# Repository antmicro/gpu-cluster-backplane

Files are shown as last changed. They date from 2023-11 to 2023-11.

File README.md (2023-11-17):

# GPU cluster backplane

Copyright (c) 2023 [Antmicro](https://www.antmicro.com)

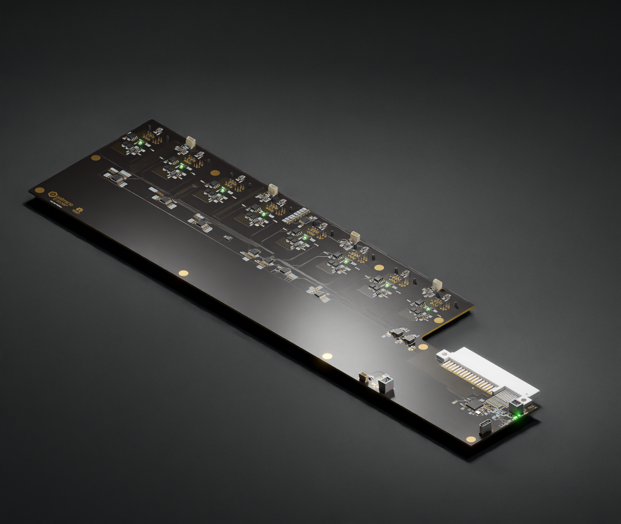
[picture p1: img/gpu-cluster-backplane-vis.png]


## Overview

This project contains open hardware design files for a PCB supporting power distribution in a cluster composed of GPUs.
This board has been derived from an open source [d166-e-psu-breakout](https://github.com/antmicro/d1600e-psu-breakout) created by Antmicro.
The GPU cluster backplane has been designed to be used with up to eight GPU units connected over a series [thunderbolt-gpu-adapters](https://github.com/antmicro/thunderbolt-gpu-adapter).
The design files for the board were prepared in KiCad 6.x.

## Key features

* Power supply distribution between eight expansion slots
* Built-in circuitry for driving cooling fans for the GPUs

## Project structure 

The main directory contains KiCad PCB project files, a LICENSE and a README.
The remaining files are stored in the following directories: 

* `lib` - contains the component libraries
* `img` - contains graphics for this README
* `doc` - contains board schematics in PDF format
* `assets` - contains visual assets for showcasing this design on [Open Hardware Portal](https://openhardware.antmicro.com) 

## License

This project is published under the [Apache-2.0](LICENSE) license.

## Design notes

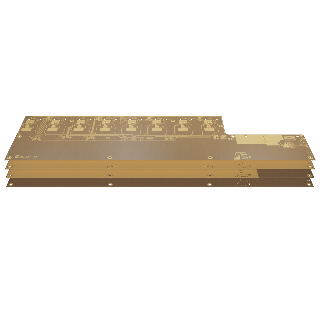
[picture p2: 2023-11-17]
assets/previews/layer1_thumbnail.webp

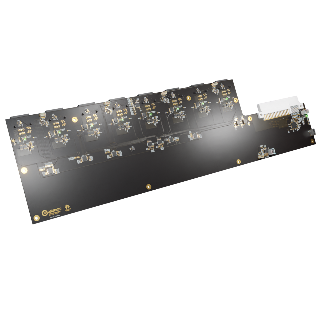
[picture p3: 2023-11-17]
assets/previews/leftT_thumbnail.png

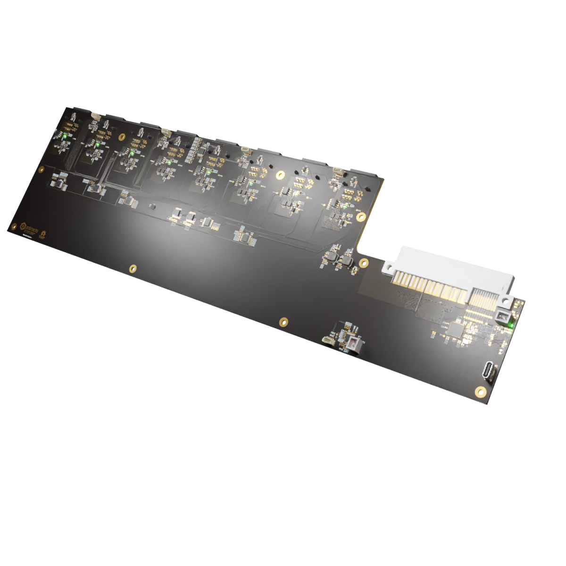
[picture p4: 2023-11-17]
assets/previews/rightT.webp

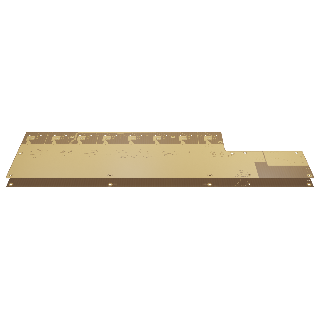
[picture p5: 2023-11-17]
assets/previews/layer3_thumbnail.webp

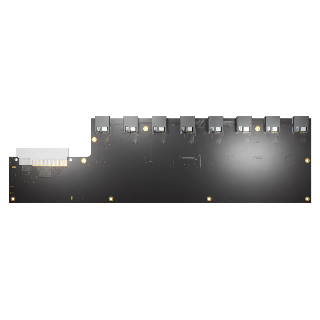
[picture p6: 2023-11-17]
assets/previews/orthoB_thumbnail.webp

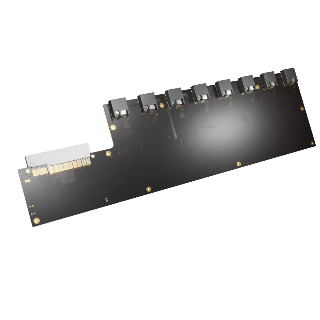
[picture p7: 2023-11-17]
assets/previews/leftB_thumbnail.png

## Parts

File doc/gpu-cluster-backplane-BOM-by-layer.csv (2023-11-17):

Reference | Quantity | Value | Footprint | Manufacturer | MPN | Layer
C1 C14 | 2 | C_10u_25V_0603 | C_0603_1608Metric | TDK | C1608X5R1E106M080AC | Top
C10 C11 C22 C23 | 4 | C_22u_16V_0603 | C_0603_1608Metric | Samsung Electro-Mechanics | CL10A226MO7JZNC | Top
C19 C92 | 2 | C_3u3_0402 | C_0402_1005Metric | TDK | C1005JB1A335K050BC | Top
C2 C59 C60 C70 C76 C77 | 6 | C_4u7_0402 | C_0402_1005Metric | Murata | GRM155R61A475MEAAD | Top
C25 C26 C27 C28 C29 C30 C31 C32 | 8 | C_10u_16V_0603 | C_0603_1608Metric | Murata | GRM188C81C106MA73D | Top
C3 C8 | 2 | C_18p_0402 | C_0402_1005Metric | Samsung Electro-Mechanics | CL05C180JB51PNC | Top
C45 C48 | 2 | C_1u_16V_0402 | C_0402_1005Metric | KEMET | C0402C105M4PACTU | Top
C5 C6 C7 C9 C12 C13 C15 C16 C17 C18 C20 C21 C24 C33 C34 C35 C36 C37 C38 C39 C40 C41 C42 C43 C44 C46 C47 C49 C50 C51 C52 C53 C54 C55 C57 C58 C61 C62 C63 C64 C66 C67 C68 C72 C75 C79 C80 C82 C84 C85 C86 C89 C93 C94 C95 C96 C97 C98 C99 C100 C101 C102 C103 C104 C105 | 65 | C_100n_0402 | C_0402_1005Metric | Murata | GRM155R61H104KE14D | Top
C56 C73 C74 C78 C87 C91 | 6 | C_2u2_0402 | C_0402_1005Metric | TDK | C1005X5R1A225K050BC | Top
C69 C71 | 2 | C_22p_0402 | C_0402_1005Metric | YAGEO | CC0402JRNPO9BN220 | Top
C81 C83 | 2 | C_16p_0402 | C_0402_1005Metric | Walsin | 0402N160J500CT | Top
C88 C90 | 2 | C_10p_0402 | C_0402_1005Metric | Murata | GCM1555C1H100GA16D | Top
D1 D2 D5 D12 D16 D19 D22 D25 D28 D31 D34 D41 | 12 | LED_G_0603_LG_L29K-G2J1-24-Z | LED_0603_1608Metric_G | OSRAM | LG L29K-G2J1-24-Z | Top
D3 D13 D14 | 3 | PESD5V0S2BQA | TPD2E009DRTR | Nexperia | PESD5V0S2BQA | Top
D36 D37 D38 D39 D44 | 5 | ESD9X5.0ST5G | SOD-923 | ON Semiconductor | ESD9X5.0ST5G | Top
D4 D15 D18 D21 D24 D27 D30 D33 | 8 |  |  |  |  | Top
D40 D43 | 2 | TPD2E009_SOT-9X3 | SOT-723 | Texas Instruments | TPD2E009DRTR | Top
D42 | 1 | LED_R_0603_KP-1608EC | LED_0603_1608Metric_R | Kingbright | KP-1608EC | Top
D6 D17 D20 D23 D26 D29 D32 D35 D45 | 9 | ESDA25P35-1U1M | ESDA25P35-1U1M | STMicroelectronics | ESDA25P35-1U1M | Top
D7 D8 D9 D10 D11 | 5 | 1N4148WS-7-F | SOD-323 | Diodes Incorporated | 1N4148WS-7-F | Top
FB1 FB2 FB10 | 3 | FB_600Z_0.5A_Murata-BLM18AG_0603 | FB_0603_1608Metric | Murata | BLM18AG601SN1D | Top
FB13 FB14 FB16 FB17 | 4 | FB_120Z_2A_Murata-BLM18PG_0603 | FB_0603_1608Metric | Murata | BLM18PG121SN1D | Top
FB3 FB4 | 2 | FB_30Z_8.5A_Murata-BLM21SN_0805 | FB_0805_2012Metric | Murata | BLM21SN300SZ1D | Top
FB5 FB6 FB7 FB8 FB9 | 5 | FB_120Z_3A_Murata-BLM18SG_0603 | FB_0603_1608Metric | Murata | BLM18SG121TN1D | Top
J17 J19 | 2 |  |  |  |  | Top
J18 | 1 | JST_SH_1x4_SM04B-SRSS-TB-LF-SN | Conn_JST_SH_1x4_SM04B-SRSS-TB-LF-SN | JST Automotive Connectors | SM04B-SRSS-TB(LF)(SN) | Top
J2 J9 | 2 | JST_XH_1x2_B2B-XH-A-LF-SN | Conn_JST_XH_1x2_B2B-XH-A-LF-SN | JST Automotive Connectors | B2B-XH-A(LF)(SN) | Top
J3 J4 J5 J6 J7 | 5 | JST_SH_1x4_BM04B-SRSS-TB-LF-SN | Conn_JST_SH_1x4_BM04B-SRSS-TB-LF-SN | JST Automotive Connectors | BM04B-SRSS-TB(LF)(SN) | Top
J8 | 1 | Socket_10107844-002LF | Socket_10107844-002LF | Amphenol | 10107844-002LF | Top
L1 L2 | 2 | L_3u3_4.1A_WE-LHMI-5030 | L_WE-LHMI-5030 | Würth Elektronik | 74437336033 | Top
MP1 MP2 MP3 MP4 MP5 MP6 MP7 MP8 MP9 | 9 | MP_Pad6mm_Drill3mm | MP_Pad6mm_Drill3mm |  |  | Top
N1 | 1 | antmicro_logo | antmicro-logo |  |  | Top
N2 | 1 | oshw_logo | oshw-logo |  |  | Top
Q1 Q4 Q5 Q6 Q7 Q8 Q11 Q14 Q17 Q20 Q23 Q26 | 12 | BSS138PW | SC70-3 | Nexperia | BSS138PW | Top
Q2 Q3 Q9 Q10 Q12 Q13 Q15 Q16 Q18 Q19 Q21 Q22 Q24 Q25 Q27 Q28 | 16 | SI7613DN-T1-GE3 | Vishay_PowerPAK_1212-8_Single | Vishay | SI7613DN-T1-GE3 | Top
Q29 | 1 | BC807-25W | SOT-323 | ON Semiconductor | SBC807-40WT1G | Top
R1 R2 | 2 | R_330R_0402 | R_0402_1005Metric | Bourns | CR0402-FX-3300GLF | Top
R10 R11 R12 R25 R29 R42 R52 R55 R63 R64 R65 R66 R67 R68 R69 R70 R71 R76 R77 R88 R91 R92 R94 R97 R98 R101 R129 R131 R132 R135 R137 R140 R164 R168 R170 R172 R174 R177 R178 R181 R183 R190 R194 R201 R205 R212 R216 R223 R227 R234 R238 R245 R249 R257 R258 R259 R260 R261 R263 R264 R273 | 61 | R_0R_0402 | R_0402_1005Metric | Panasonic | ERJ2GE0R00X | Top
R13 R14 R21 R102 R103 R136 R141 R160 R165 R175 R186 R191 R197 R202 R208 R213 R219 R224 R230 R235 R241 R246 | 22 | R_4k7_0402 | R_0402_1005Metric | Bourns | CR0402-FX-4701GLF | Top
R22 R161 R163 R187 R189 R198 R200 R209 R211 R220 R222 R231 R233 R242 R244 | 15 | R_2R_0402 | R_0402_1005Metric | Bourns | CR0402-FX-2R00GLF | Top
R256 R270 | 2 | R_470R_0402 | R_0402_1005Metric | Bourns | CR0402-FX-4700GLF | Top
R27 R166 R192 R203 R214 R225 R236 R247 R272 R278 R282 R286 R288 | 13 | R_100k_0402 | R_0402_1005Metric | Bourns | CR0402-FX-1003GLF | Top
R279 R280 | 2 | R_100R_0402 | R_0402_1005Metric | Bourns | CR0402-FX-1000GLF | Top
R28 R167 R193 R204 R215 R226 R237 R248 | 8 | R_15k_0.1%_0402 | R_0402_1005Metric | Panasonic | ERA-2ARB153X | Top
R299 | 1 | R_6k34_0402 | R_0402_1005Metric | Bourns | CR0402-FX-6341GLF | Top
R3 R87 R89 R105 R108 R111 R114 R117 R120 R123 R126 R252 R253 R289 R290 | 15 | R_5k1_0402 | R_0402_1005Metric | Bourns | CR0402-FX-5101GLF | Top
R36 R38 R39 R40 R41 R44 R45 R46 R47 R48 R49 R50 R51 | 13 | R_51k_0402 | R_0402_1005Metric | Bourns | CR0402-FX-5102GLF | Top
R4 R19 R72 R73 R74 R75 R78 R79 R80 R81 R82 R104 R106 R107 R109 R110 R112 R113 R115 R116 R118 R119 R121 R122 R124 R125 R127 R142 R143 R144 R145 R146 R147 R148 R149 R150 R151 R152 R153 R154 R155 R156 R157 R158 R184 R195 R206 R217 R228 R239 R291 R292 R293 R294 R295 R296 R297 R298 R301 | 59 | R_10k_0402 | R_0402_1005Metric | Bourns | CR0402-FX-1002GLF | Top
R5 R254 | 2 | R_1k_0402 | R_0402_1005Metric | Bourns | CR0402-FX-1001GLF | Top
R56 R57 R58 R59 | 4 | R_510k_0402 | R_0402_1005Metric | Bourns | CR0402-FX-5103GLF | Top
R6 | 1 | R_10k7_0402 | R_0402_1005Metric | Bourns | CR0402-FX-1072GLF | Top
R7 R300 | 2 | R_2k_0402 | R_0402_1005Metric | Bourns | CR0402-FX-2001GLF | Top
R8 R255 | 2 | R_12k_0402 | R_0402_1005Metric | Bourns | CR0402-FX-1202GLF | Top
R84 R302 | 2 | R_0R_0805 | R_0805_2012Metric | Vishay | CRCW08050000Z0EA | Top
R85 | 1 | R_680R_0402 | R_0402_1005Metric | Bourns | CR0402-FX-6800GLF | Top
TP1 TP2 TP3 TP4 TP5 TP7 TP8 TP9 TP10 TP11 TP12 TP13 TP14 TP15 TP16 TP17 TP18 TP19 TP20 TP21 TP22 TP23 TP24 TP25 TP26 TP27 TP28 TP29 TP30 TP31 TP32 TP33 TP34 TP35 TP36 TP37 TP38 TP39 TP40 TP41 TP42 TP43 TP44 TP45 TP46 TP47 TP48 TP49 TP50 TP51 TP52 TP53 TP54 TP55 TP56 TP57 TP58 TP59 TP60 TP61 TP62 TP63 TP64 TP65 TP66 TP67 TP68 | 67 | TP_1mm_SMD | TP_SMD_1mm |  |  | Top
U1 U3 | 2 | AP62301_TSOT | TSOT23-6 | Diodes Incorporated | AP62301WU-7 | Top
U12 U13 U15 U16 U19 | 5 | TCA9534PWR_TSSOP | TSSOP-16_4.4x5mm_P0.65mm | Texas Instruments | TCA9534PWR | Top
U14 | 1 | Si7021 | DFN-6-1EP_3x3mm_P1mm_EP1.5x2.4mm | Silicon Labs | Si7021-A20-GM1R | Top
U18 U20 | 2 | ADS7828 | TSSOP-16_4.4x5mm_P0.65mm | Texas Instruments | ADS7828E/250 | Top
U2 U27 | 2 | FT4232H_VQFN | QFN-56-1EP_8x8mm_P0.5mm | FTDI Chip | FT4232H-56Q-REEL | Top
U28 | 1 | AP7370-33SA-7 | SOT-23-3 | Diodes Incorporated | AP7370-33SA-7 | Top
U29 | 1 | STM32G474CET6 | LQFP-48_B7x7mm_P0.5mm_0.20mmPadPadClearance_Pad0.30x1.20mm | STMicroelectronics | STM32G474CET6 | Top
U30 | 1 | MB85RC1MTPNF-G | SOP-8_3.9x5.05mm_P1.27mm | Fujitsu | MB85RC1MTPNF-G-JNERE1 | Top
U31 | 1 | SHT45 | Sensirion_DFN-4-1.5x1.5x0.5mm_P0.8mm | Sensirion | SHT45-AD1B-R2 | Top
U32 | 1 | BME280 | LGA-8_2.5x2.5mm_BME280 | Bosch | BME280 | Top
U33 U34 U35 U36 U37 U38 U39 U40 | 8 | SN74LV1T125DBVR | SOT-23-5 | Texas Instruments | SN74LV1T125DBVR | Top
U4 U17 U21 U22 U23 U24 U25 U26 | 8 | TMCS1100A2-Q1 | SOIC-8-1EP_3.9x4.9x1.75mm_P1.27mm | Texas Instruments | TMCS1100A2QDRQ1 | Top
U5 | 1 | LM339_TSSOP_CUSTOM_Split | TSSOP-14_4.4x5mm_P0.65mm | Texas Instruments | LM339PW | Top
U6 | 1 | MAX6643_QSOP | QSOP-16_3x4.75x0.75mm_P0.5mm | Analog Devices | MAX6643LBBAEE+ | Top
U7 U8 U9 U10 | 4 | TS5A3359_VSSOP | VSSOP-8_2.3x2mm_P0.5mm | Texas Instruments | TS5A3359DCUR | Top
Y1 | 1 | Resonator_12MHz_ABM8G | Oscillator_SMD_Geyer_KX-7-4Pin_3.2x2.5mm | Abracon | ABM8G-12.000MHZ-18-D2Y-T | Top
Y2 | 1 | Resonator_12MHz_ABM3B | ABM3B | Abracon | ABM3B-12.000MHZ-B2-T | Top
Y3 | 1 | Resonator_32.768kHz_ABS06 | Crystal_SMD_2012-2Pin_2.0x1.2mm | Abracon | ABS06-127-32.768KHZ-T | Top
Y4 | 1 | Resonator_8MHz_ABM3B | ABM3B | Abracon | ABM3B-8.000MHZ-10-1-U-T | Top
BAT1 | 1 | BAT-HLD-012-SMT-TR | BAT_BAT-HLD-012-SMT-TR | Linx Technologies | BAT-HLD-012-SMT-TR | Bottom
J1 J10 J11 J12 J13 J14 J15 J16 | 8 |  |  |  |  | Bottom
C65 | 1 | C_100n_0402 | C_0402_1005Metric | Murata | GRM155R61H104KE14D | DNP
FB11 FB12 | 2 | FB_600Z_0.5A_Murata-BLM18AG_0603 | FB_0603_1608Metric | Murata | BLM18AG601SN1D | DNP
FB15 | 1 | FB_120Z_2A_Murata-BLM18PG_0603 | FB_0603_1608Metric | Murata | BLM18PG121SN1D | DNP
R20 R159 R185 R196 R207 R218 R229 R240 | 8 | R_10k_0402 | R_0402_1005Metric | Bourns | CR0402-FX-1002GLF | DNP
R250 R251 R271 R277 | 4 | R_1M_0402 | R_0402_1005Metric | Bourns | CR0402-FX-1004GLF | DNP
R267 R268 | 2 | R_470R_0402 | R_0402_1005Metric | Bourns | CR0402-FX-4700GLF | DNP
R274 R275 R276 | 3 | R_100R_0402 | R_0402_1005Metric | Bourns | CR0402-FX-1000GLF | DNP
R281 R283 R284 R285 R287 | 5 | R_100k_0402 | R_0402_1005Metric | Bourns | CR0402-FX-1003GLF | DNP
R83 R269 | 2 | R_0R_0805 | R_0805_2012Metric | Vishay | CRCW08050000Z0EA | DNP
R9 R15 R16 R17 R18 R23 R30 R31 R32 R33 R43 R53 R54 R60 R61 R62 R86 R90 R93 R95 R96 R99 R100 R128 R130 R133 R134 R138 R139 R162 R169 R171 R173 R176 R179 R180 R182 R188 R199 R210 R221 R232 R243 R262 R265 R266 | 46 | R_0R_0402 | R_0402_1005Metric | Panasonic | ERJ2GE0R00X | DNP
SW1 | 1 | MSS3-V-T_R | Switch_Slide_MSS3 | Diptronics | MSS3-V-T/R | DNP
C4 | 1 | C_4u7_0402 | C_0402_1005Metric | Murata | GRM155R61A475MEAAD | Virtual
R24 | 1 | R_2R_0402 | R_0402_1005Metric | Bourns | CR0402-FX-2R00GLF | Virtual
R26 | 1 | R_4k7_0402 | R_0402_1005Metric | Bourns | CR0402-FX-4701GLF | Virtual
R34 R35 R37 | 3 | R_51k_0402 | R_0402_1005Metric | Bourns | CR0402-FX-5102GLF | Virtual
#FLG01 #FLG02 #FLG03 #FLG04 #FLG05 #FLG06 #FLG07 #FLG08 #FLG09 #FLG010 #FLG011 #FLG012 #FLG0101 #FLG0102 #FLG0103 #FLG0104 #FLG0105 #FLG0106 #FLG0107 #FLG0108 #FLG0109 #FLG0110 #FLG0111 #FLG0112 | 24 | PWR_FLAG |  |  |  | Unknown
#PWR0101 #PWR0106 #PWR0107 #PWR0108 #PWR0109 #PWR0110 #PWR0111 #PWR0112 #PWR0113 #PWR0114 #PWR0115 #PWR0116 #PWR0117 #PWR0118 #PWR0119 #PWR0120 #PWR0121 #PWR0122 #PWR0123 #PWR0124 #PWR0125 #PWR0126 #PWR0127 #PWR0128 #PWR0129 #PWR0130 #PWR0131 #PWR0132 #PWR0133 #PWR0134 #PWR0135 #PWR0136 #PWR0138 #PWR0139 #PWR0140 #PWR0141 #PWR0142 #PWR0143 #PWR0144 #PWR0145 #PWR0146 #PWR0147 #PWR0148 #PWR0149 #PWR0151 #PWR0153 #PWR0154 #PWR0155 #PWR0159 #PWR0161 #PWR0163 #PWR0164 #PWR0165 #PWR0166 #PWR0167 #PWR0168 #PWR0169 #PWR0170 #PWR0172 #PWR0174 #PWR0176 #PWR0177 #PWR0178 #PWR0180 #PWR0181 #PWR0182 #PWR0185 #PWR0186 #PWR0189 #PWR0191 #PWR0192 #PWR0194 #PWR0195 #PWR0196 #PWR0197 #PWR0198 #PWR0199 #PWR0200 #PWR0202 #PWR0204 #PWR0206 #PWR0207 #PWR0213 #PWR0219 #PWR0220 #PWR0222 #PWR0225 #PWR0226 #PWR0227 #PWR0230 #PWR0231 #PWR0233 #PWR0235 #PWR0237 #PWR0239 #PWR0241 #PWR0243 #PWR0249 #PWR0250 #PWR0251 #PWR0252 #PWR0253 #PWR0255 #PWR0256 #PWR0257 #PWR0259 #PWR0260 #PWR0261 #PWR0262 #PWR0265 #PWR0266 #PWR0267 #PWR0269 #PWR0270 #PWR0271 #PWR0272 #PWR0273 #PWR0275 #PWR0276 #PWR0277 #PWR0279 #PWR0280 #PWR0281 #PWR0282 #PWR0283 #PWR0285 #PWR0286 #PWR0287 #PWR0289 #PWR0290 #PWR0291 #PWR0292 #PWR0293 #PWR0295 #PWR0296 #PWR0297 #PWR0299 #PWR0300 #PWR0301 #PWR0302 #PWR0303 #PWR0304 #PWR0305 #PWR0306 #PWR0307 #PWR0308 #PWR0310 #PWR0311 #PWR0312 #PWR0313 #PWR0314 #PWR0315 #PWR0316 #PWR0317 #PWR0318 #PWR0319 #PWR0320 #PWR0321 #PWR0322 #PWR0323 #PWR0324 #PWR0325 #PWR0326 #PWR0327 #PWR0328 #PWR0329 #PWR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 | 287 | GND |  |  |  | Unknown
#PWR02 #PWR08 #PWR013 #PWR019 #PWR024 #PWR025 #PWR040 #PWR041 #PWR045 #PWR051 #PWR053 #PWR055 #PWR073 #PWR077 #PWR079 #PWR081 #PWR083 #PWR084 #PWR085 #PWR086 #PWR087 #PWR088 #PWR0100 #PWR0137 #PWR0150 #PWR0152 #PWR0156 #PWR0157 #PWR0158 #PWR0160 #PWR0162 #PWR0171 #PWR0173 #PWR0175 #PWR0179 #PWR0183 #PWR0184 #PWR0187 #PWR0188 #PWR0190 #PWR0193 #PWR0201 #PWR0203 #PWR0205 #PWR0209 #PWR0215 #PWR0218 #PWR0221 #PWR0223 #PWR0224 #PWR0228 #PWR0229 #PWR0232 #PWR0234 #PWR0236 #PWR0240 #PWR0242 #PWR0244 #PWR0248 #PWR0254 #PWR0258 #PWR0263 #PWR0264 #PWR0268 #PWR0274 #PWR0278 #PWR0284 #PWR0288 #PWR0294 #PWR0298 #PWR0337 | 71 | +3V3 |  |  |  | Unknown
#PWR023 #PWR075 #PWR090 #PWR091 #PWR092 #PWR093 #PWR095 #PWR096 #PWR097 #PWR098 #PWR0102 #PWR0103 #PWR0104 #PWR0105 #PWR0380 #PWR0383 #PWR0384 #PWR0387 #PWR0388 #PWR0391 #PWR0392 #PWR0395 #PWR0396 #PWR0399 #PWR0400 #PWR0403 #PWR0404 #PWR0407 #PWR0408 #PWR0411 | 30 | +5V |  |  |  | Unknown
#PWR04 #PWR0309 | 2 | GNDREF |  |  |  | Unknown

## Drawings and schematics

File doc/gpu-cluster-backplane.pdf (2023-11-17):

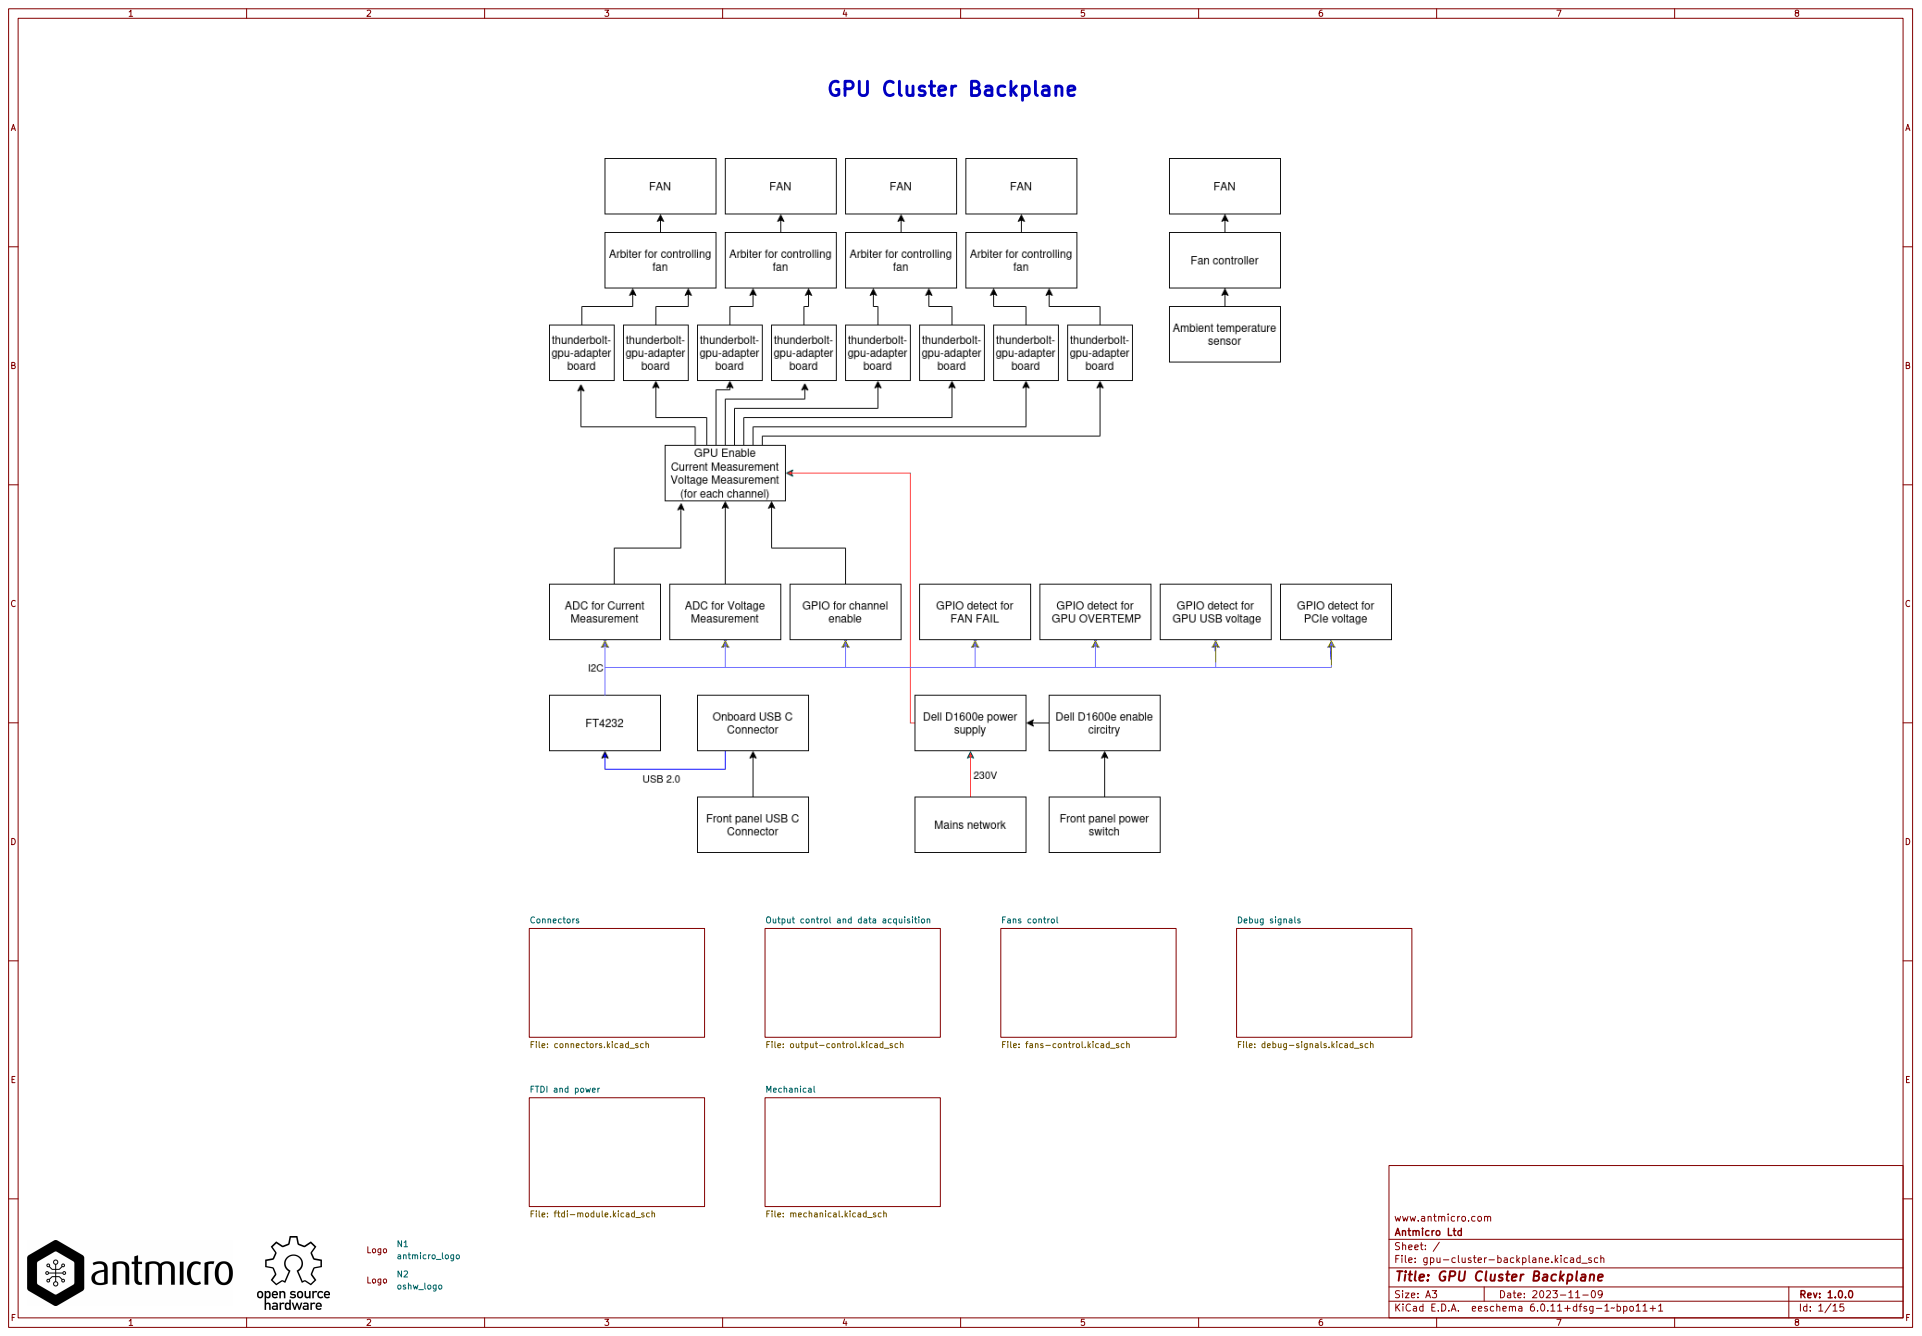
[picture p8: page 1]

Id: 1/15 Title: GPU Cluster Backplane

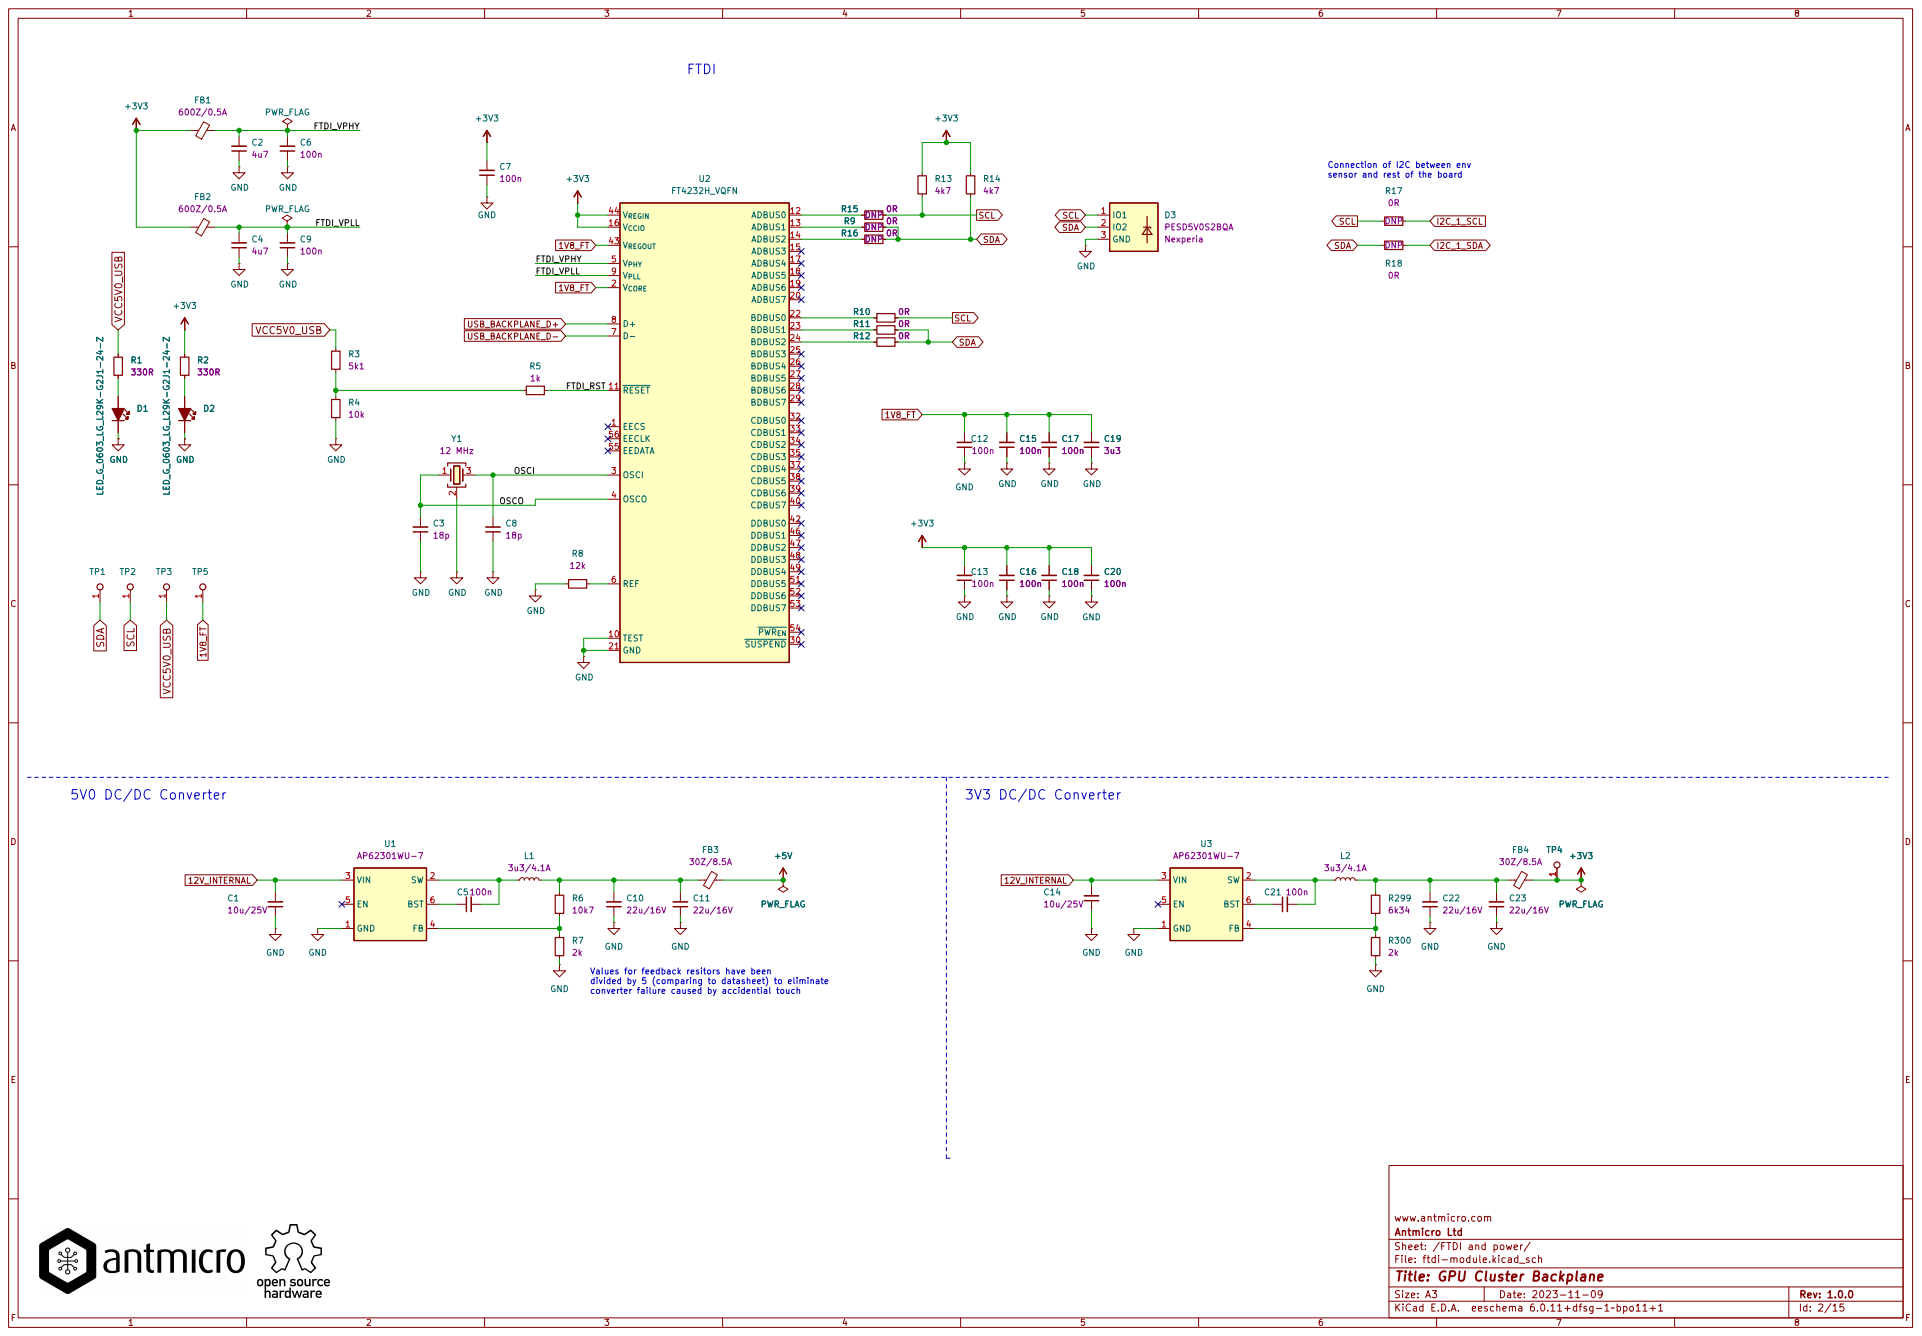
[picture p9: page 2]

sensor and rest of the board FTDI

Id: 2/15 Title: GPU Cluster Backplane

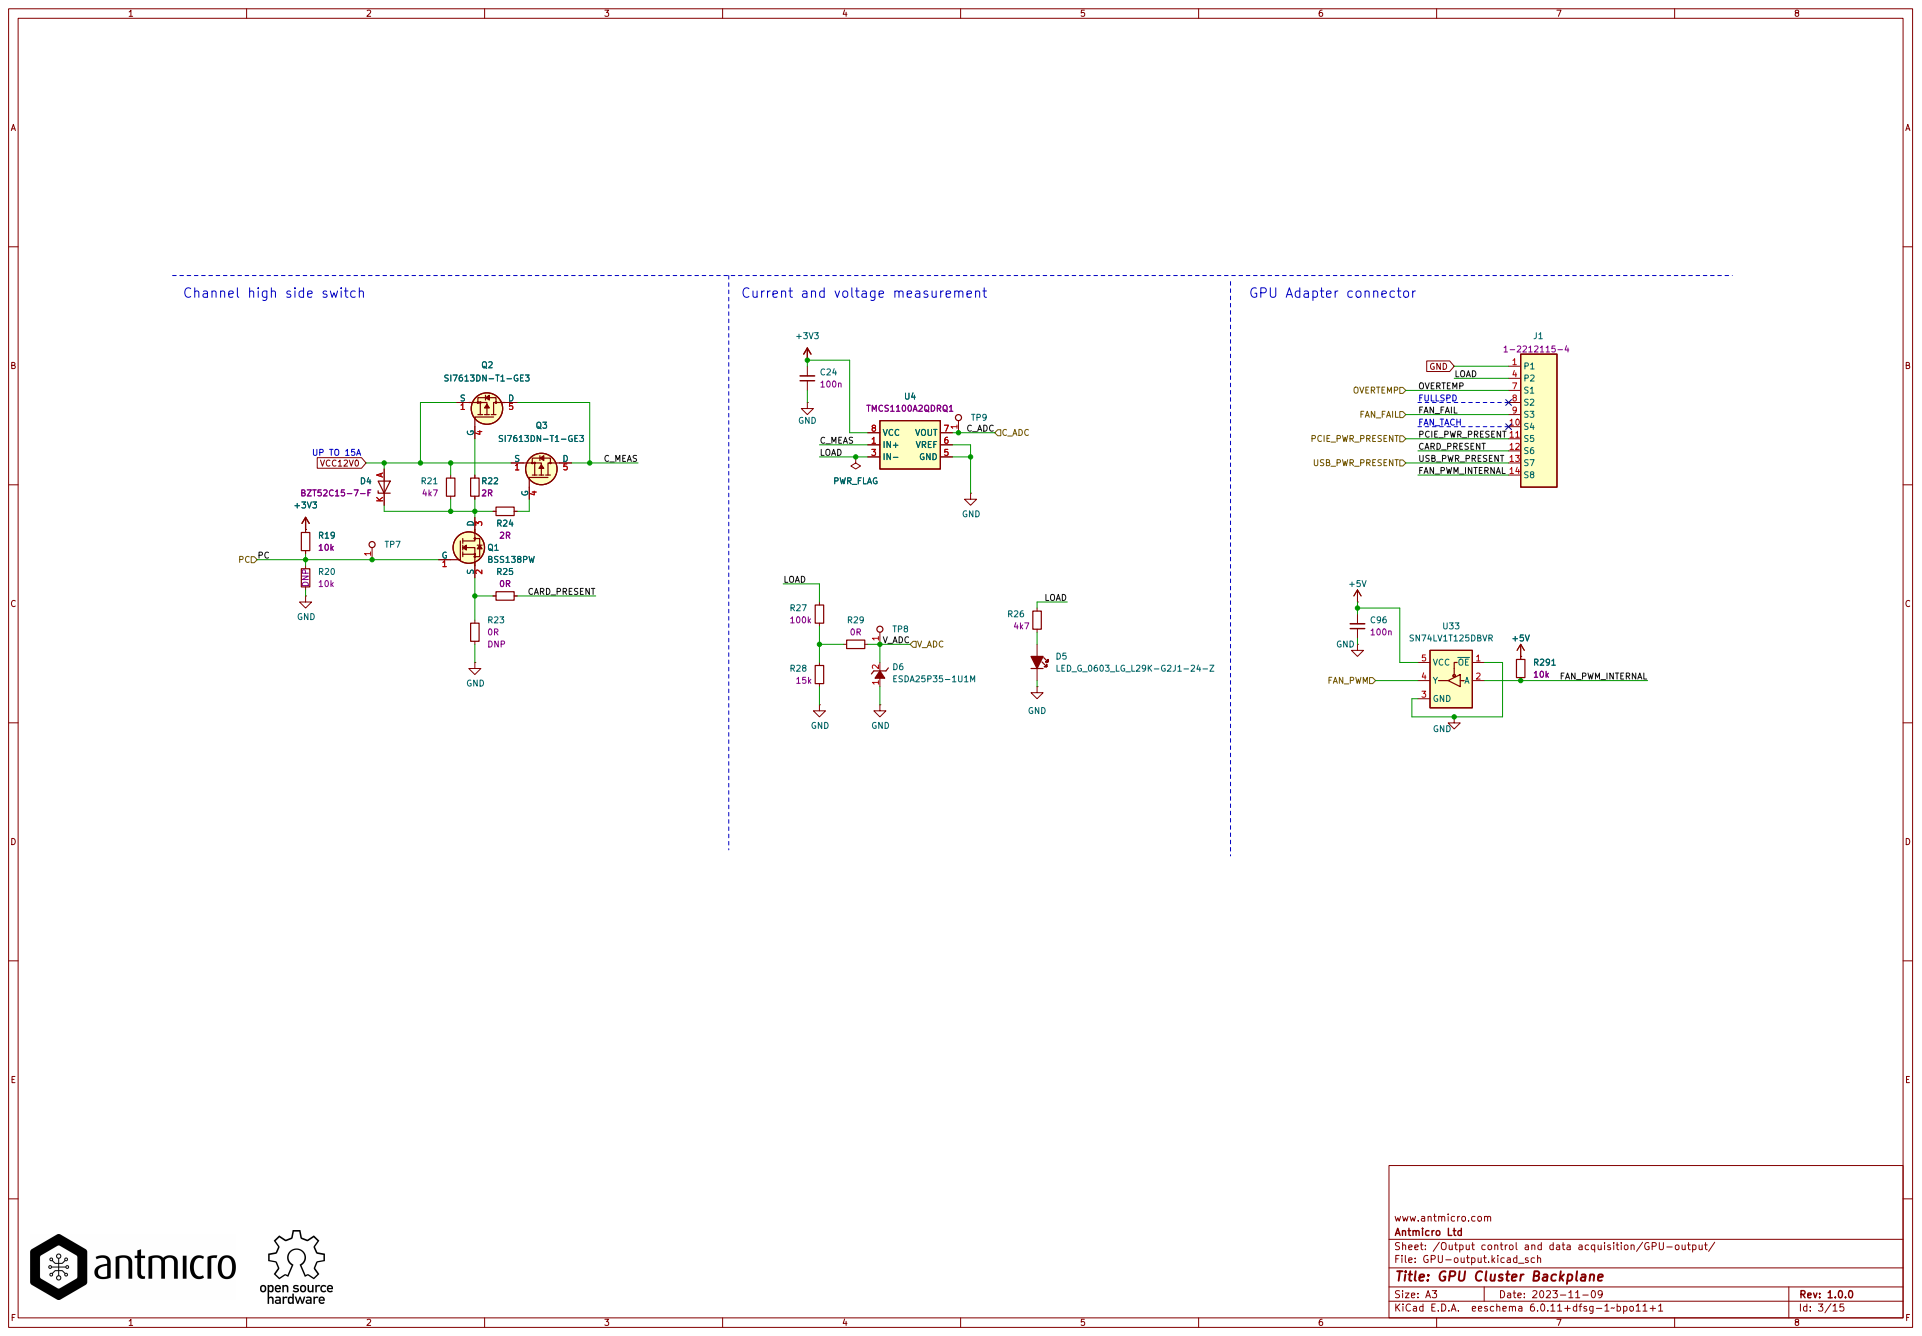
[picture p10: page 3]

Id: 3/15 Title: GPU Cluster Backplane

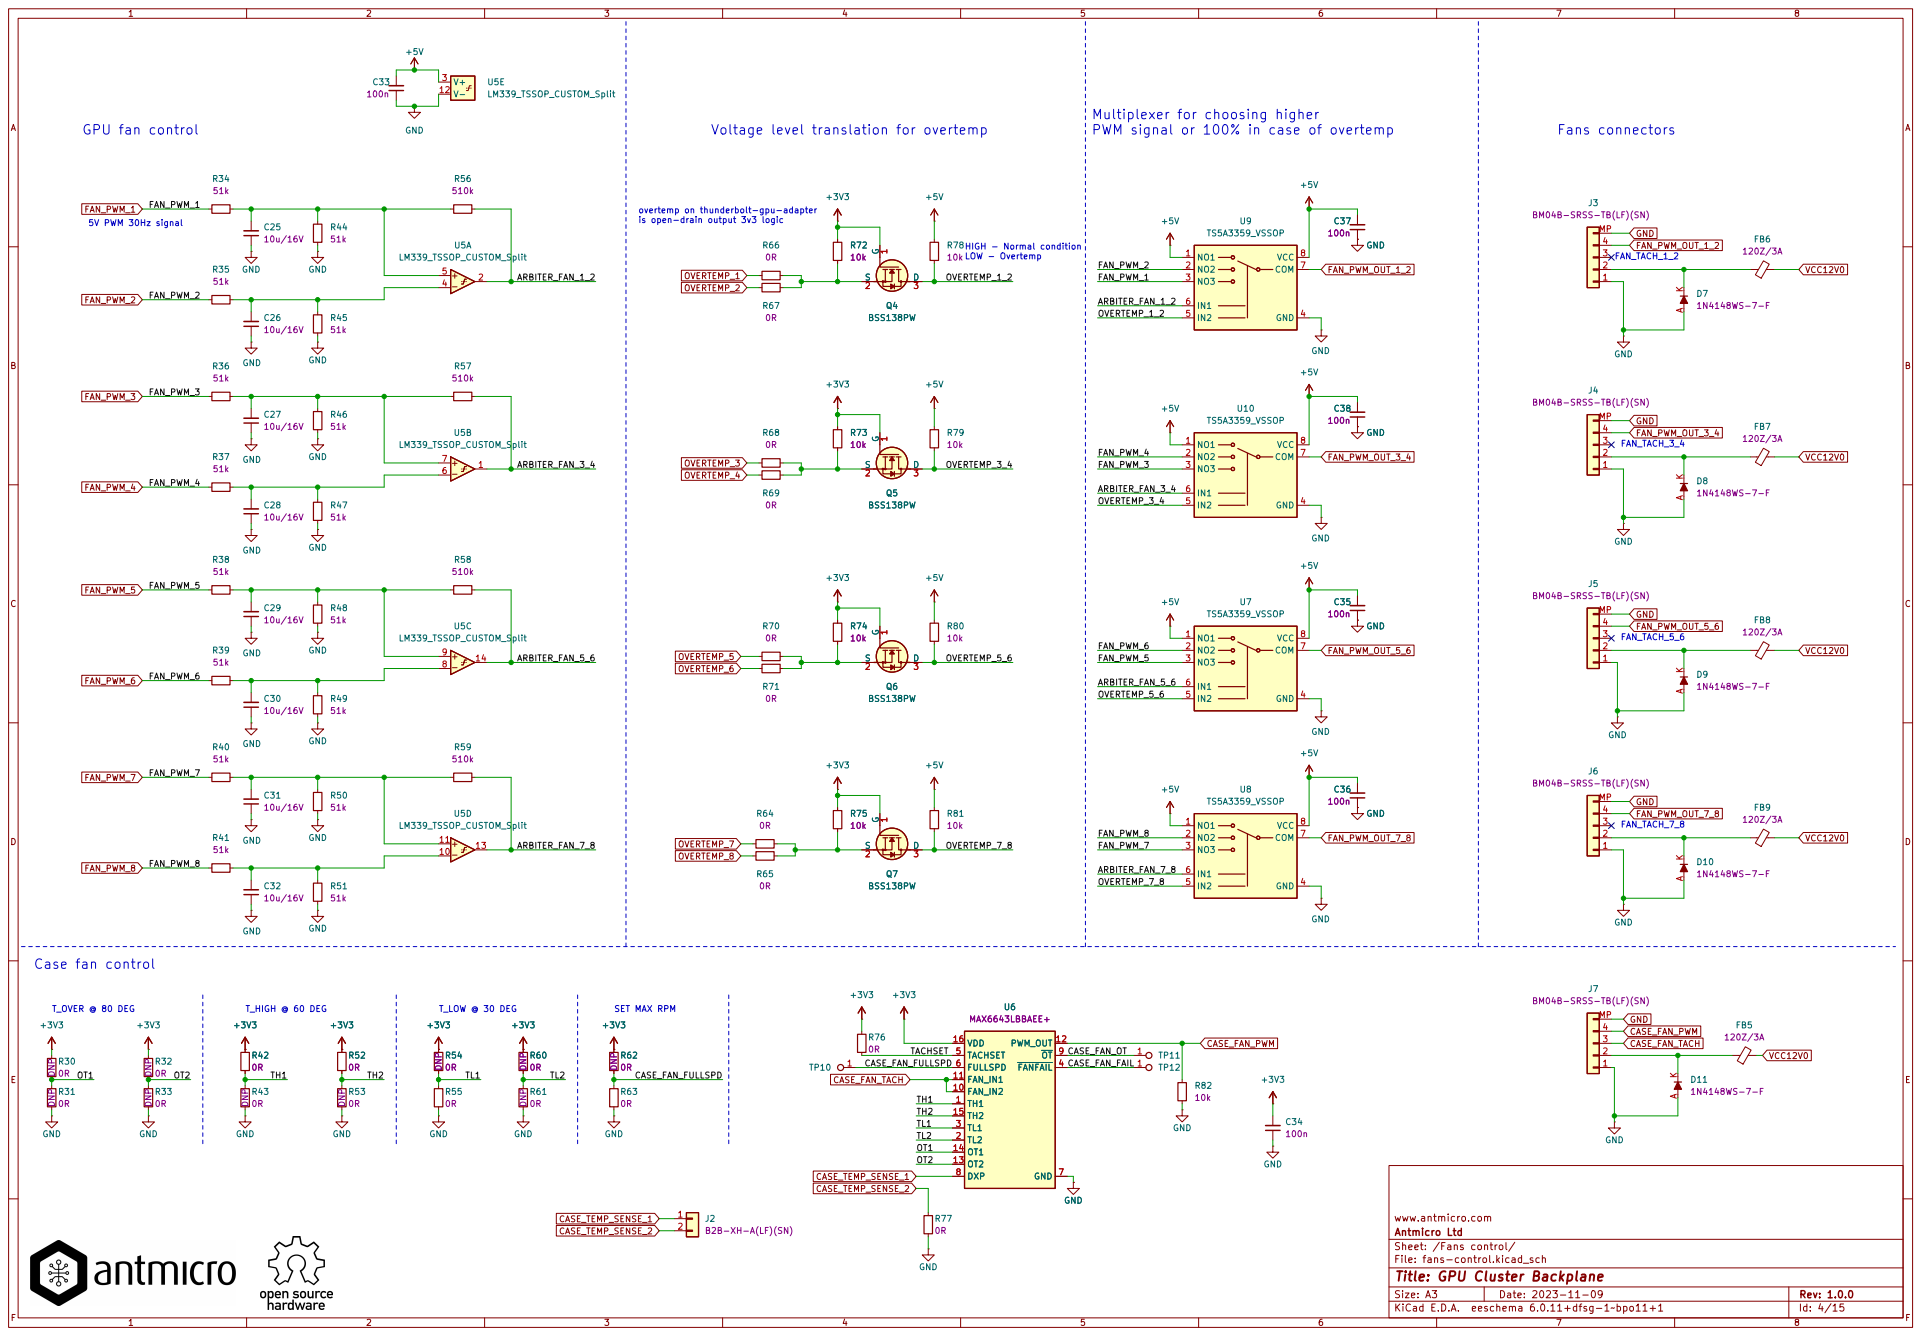
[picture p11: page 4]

J3 BM04B-SRSS-TB(LF)(SN) +5V

overtemp on thunderbolt-gpu-adapter

J4 BM04B-SRSS-TB(LF)(SN) GND

J5 BM04B-SRSS-TB(LF)(SN) R53 DNP 0R

J6 BM04B-SRSS-TB(LF)(SN) GND

J7 BM04B-SRSS-TB(LF)(SN) GND

Id: 4/15 Title: GPU Cluster Backplane

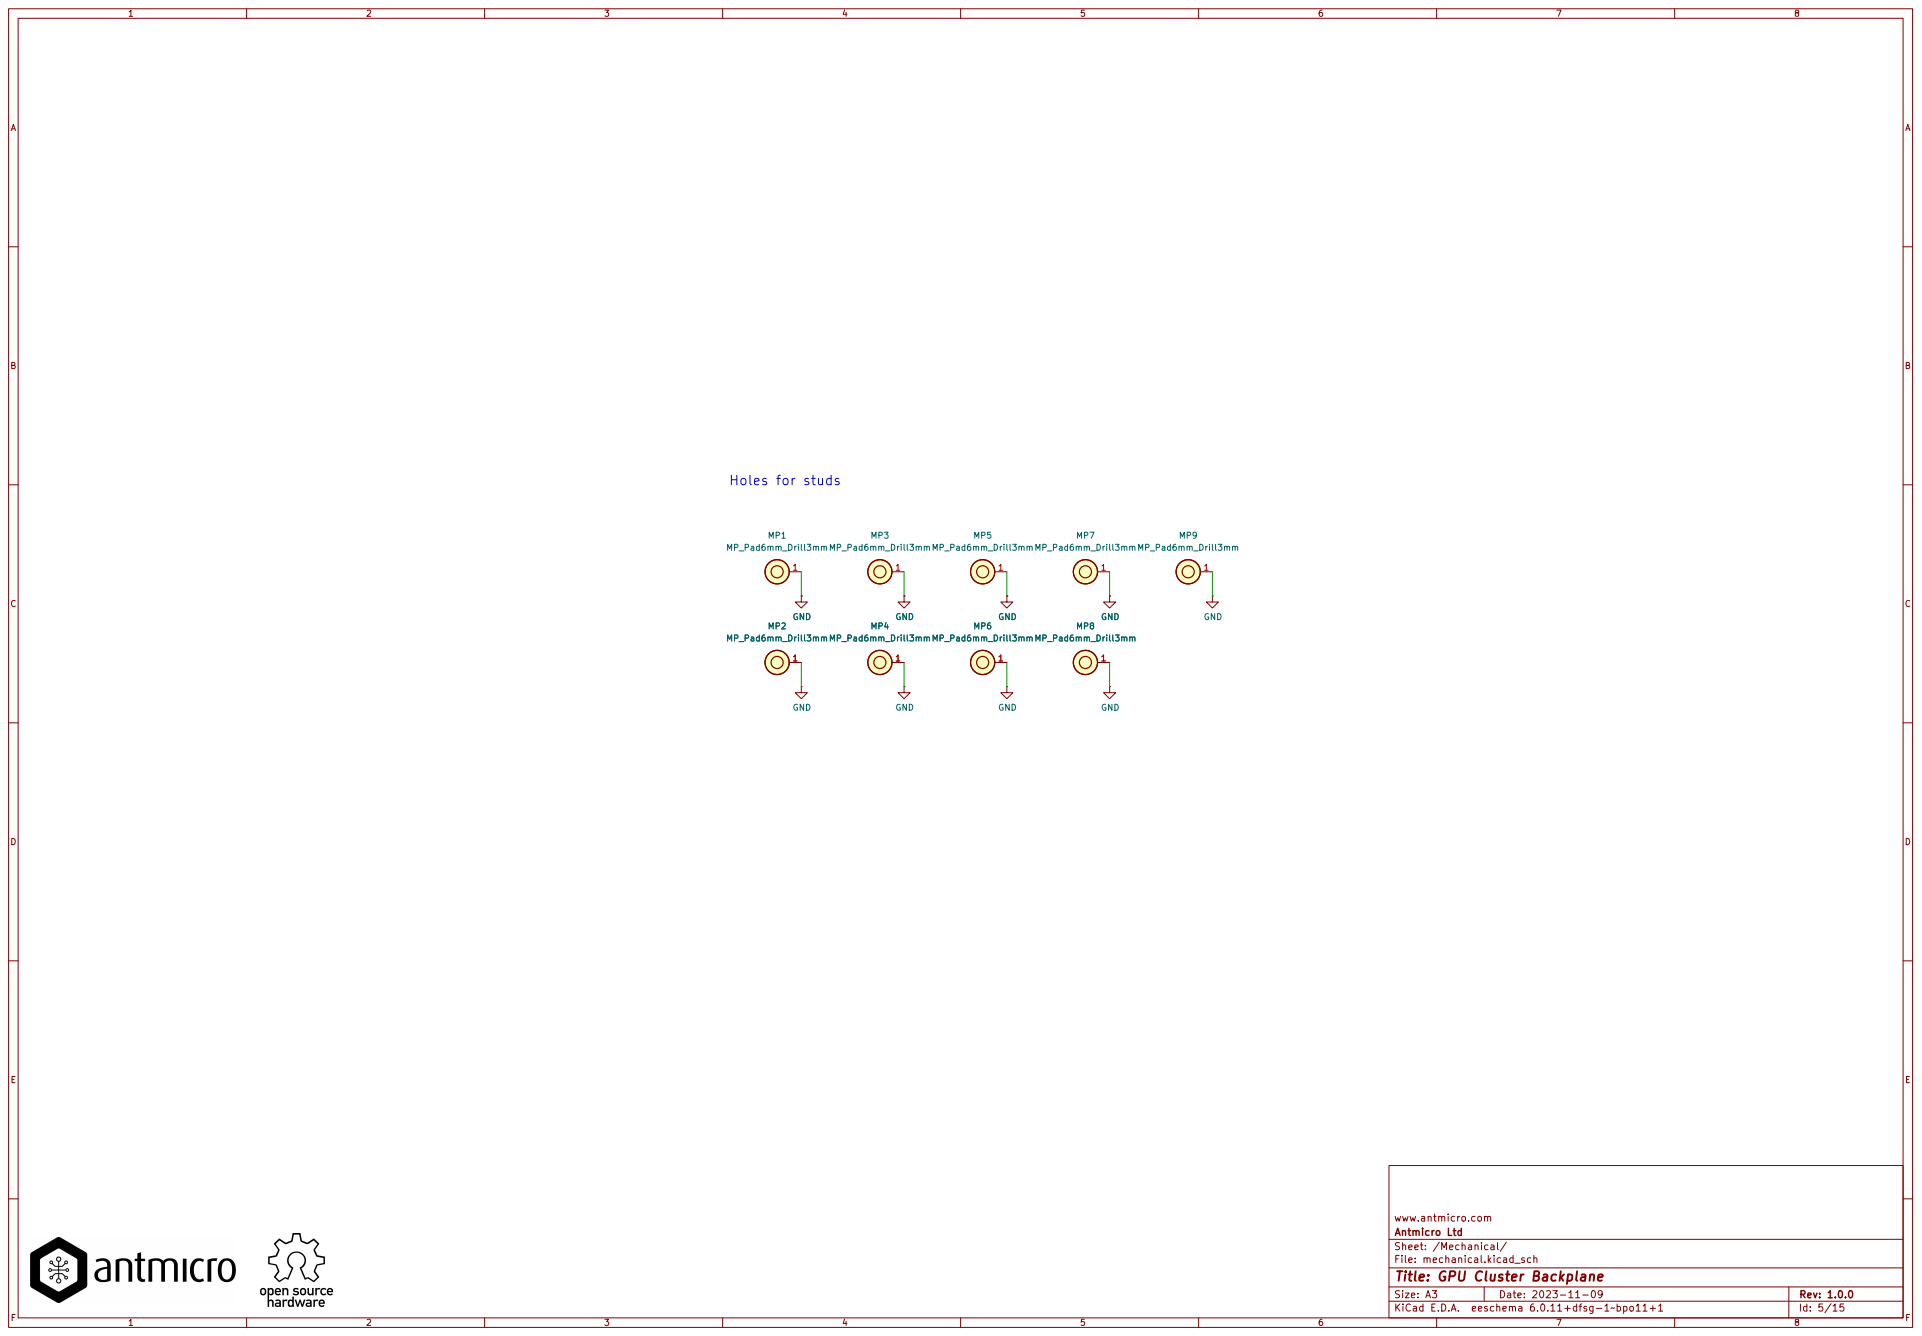
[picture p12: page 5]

Id: 5/15 Title: GPU Cluster Backplane

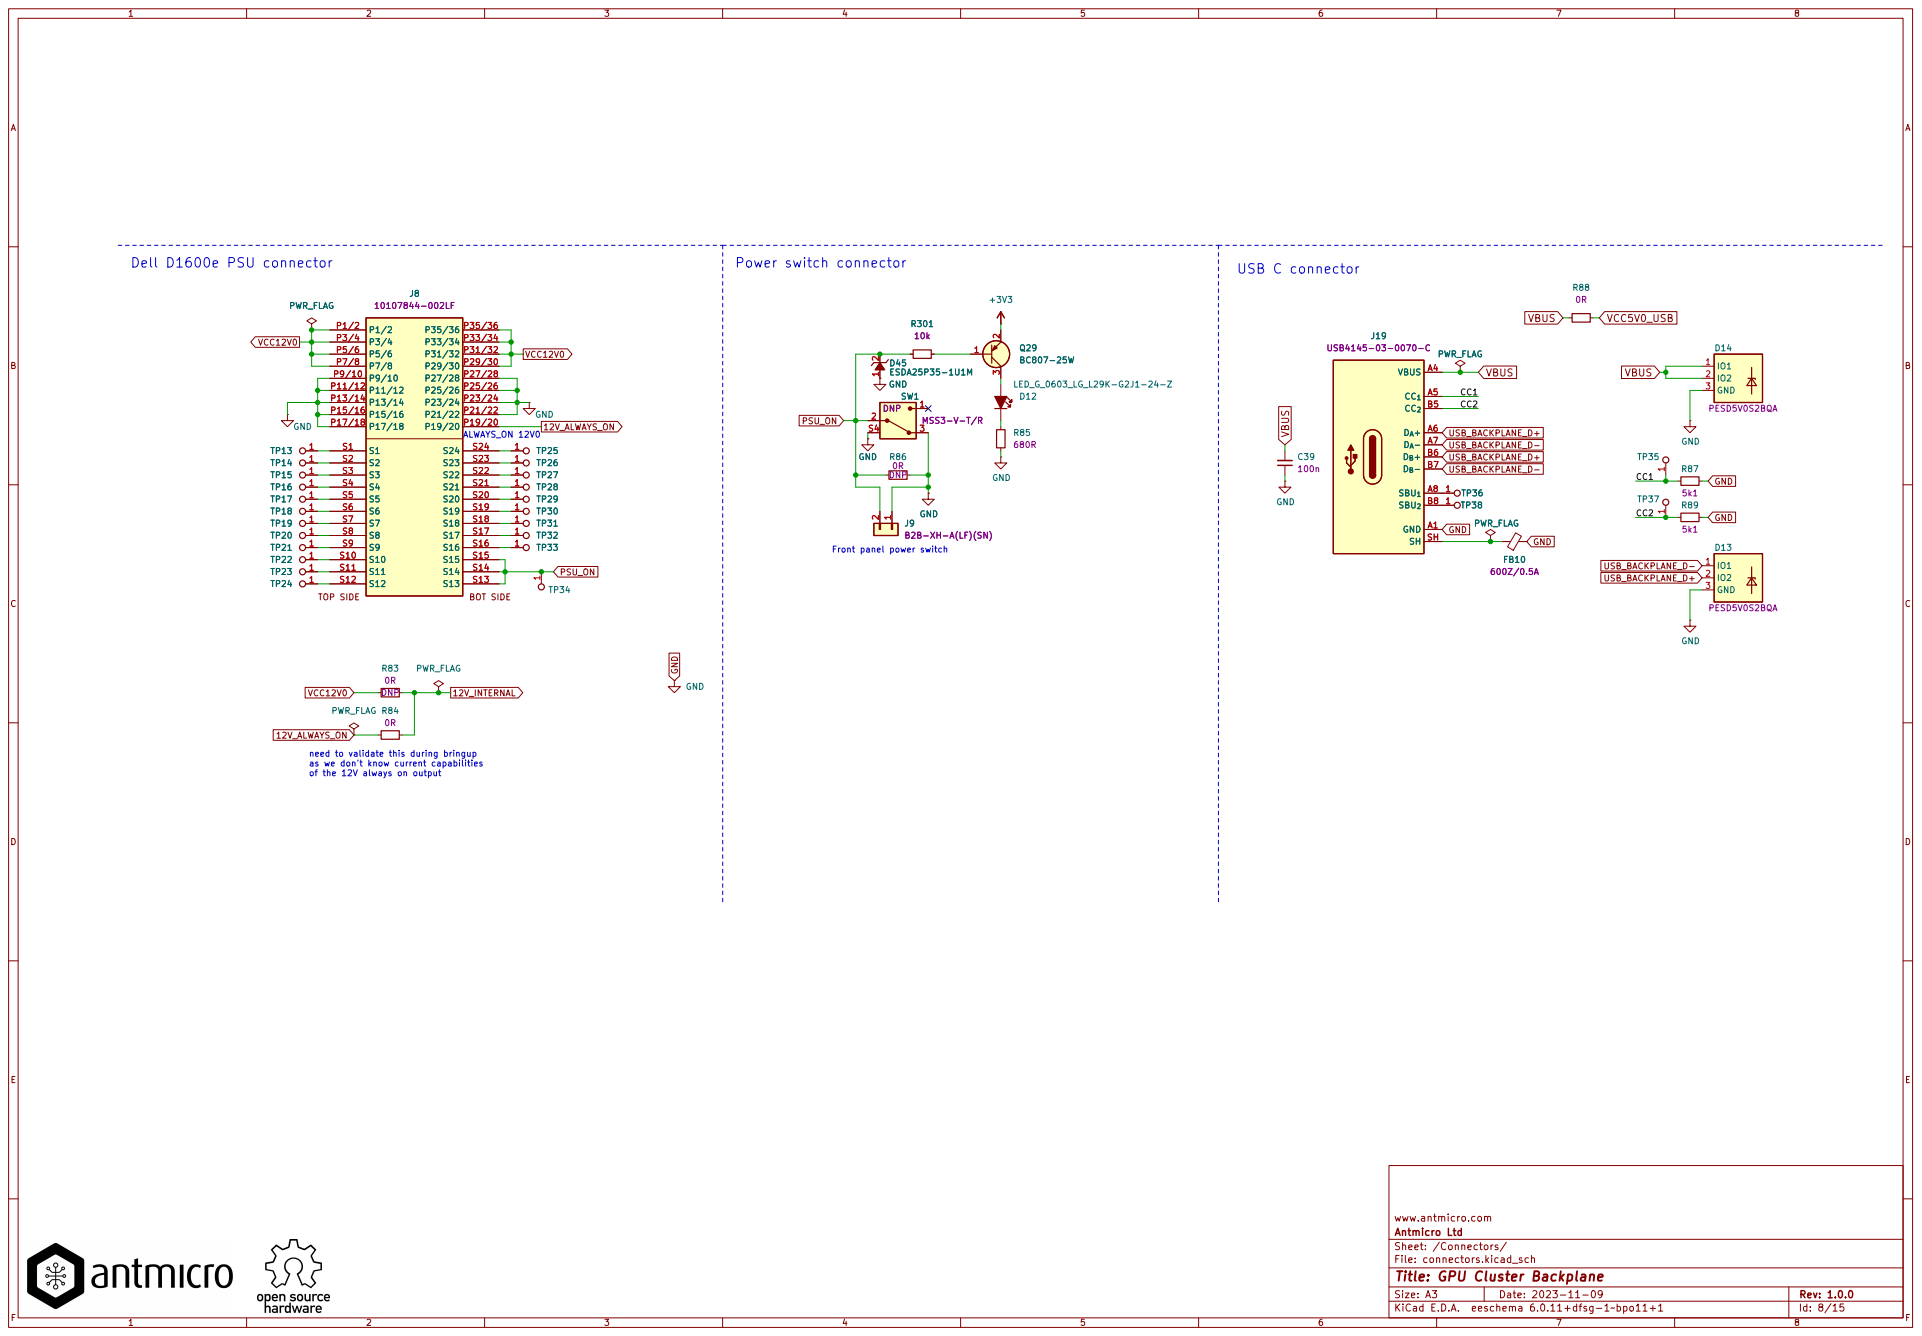
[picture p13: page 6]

J9B2B-XH-A(LF)(SN) GND

Id: 8/15 Title: GPU Cluster Backplane

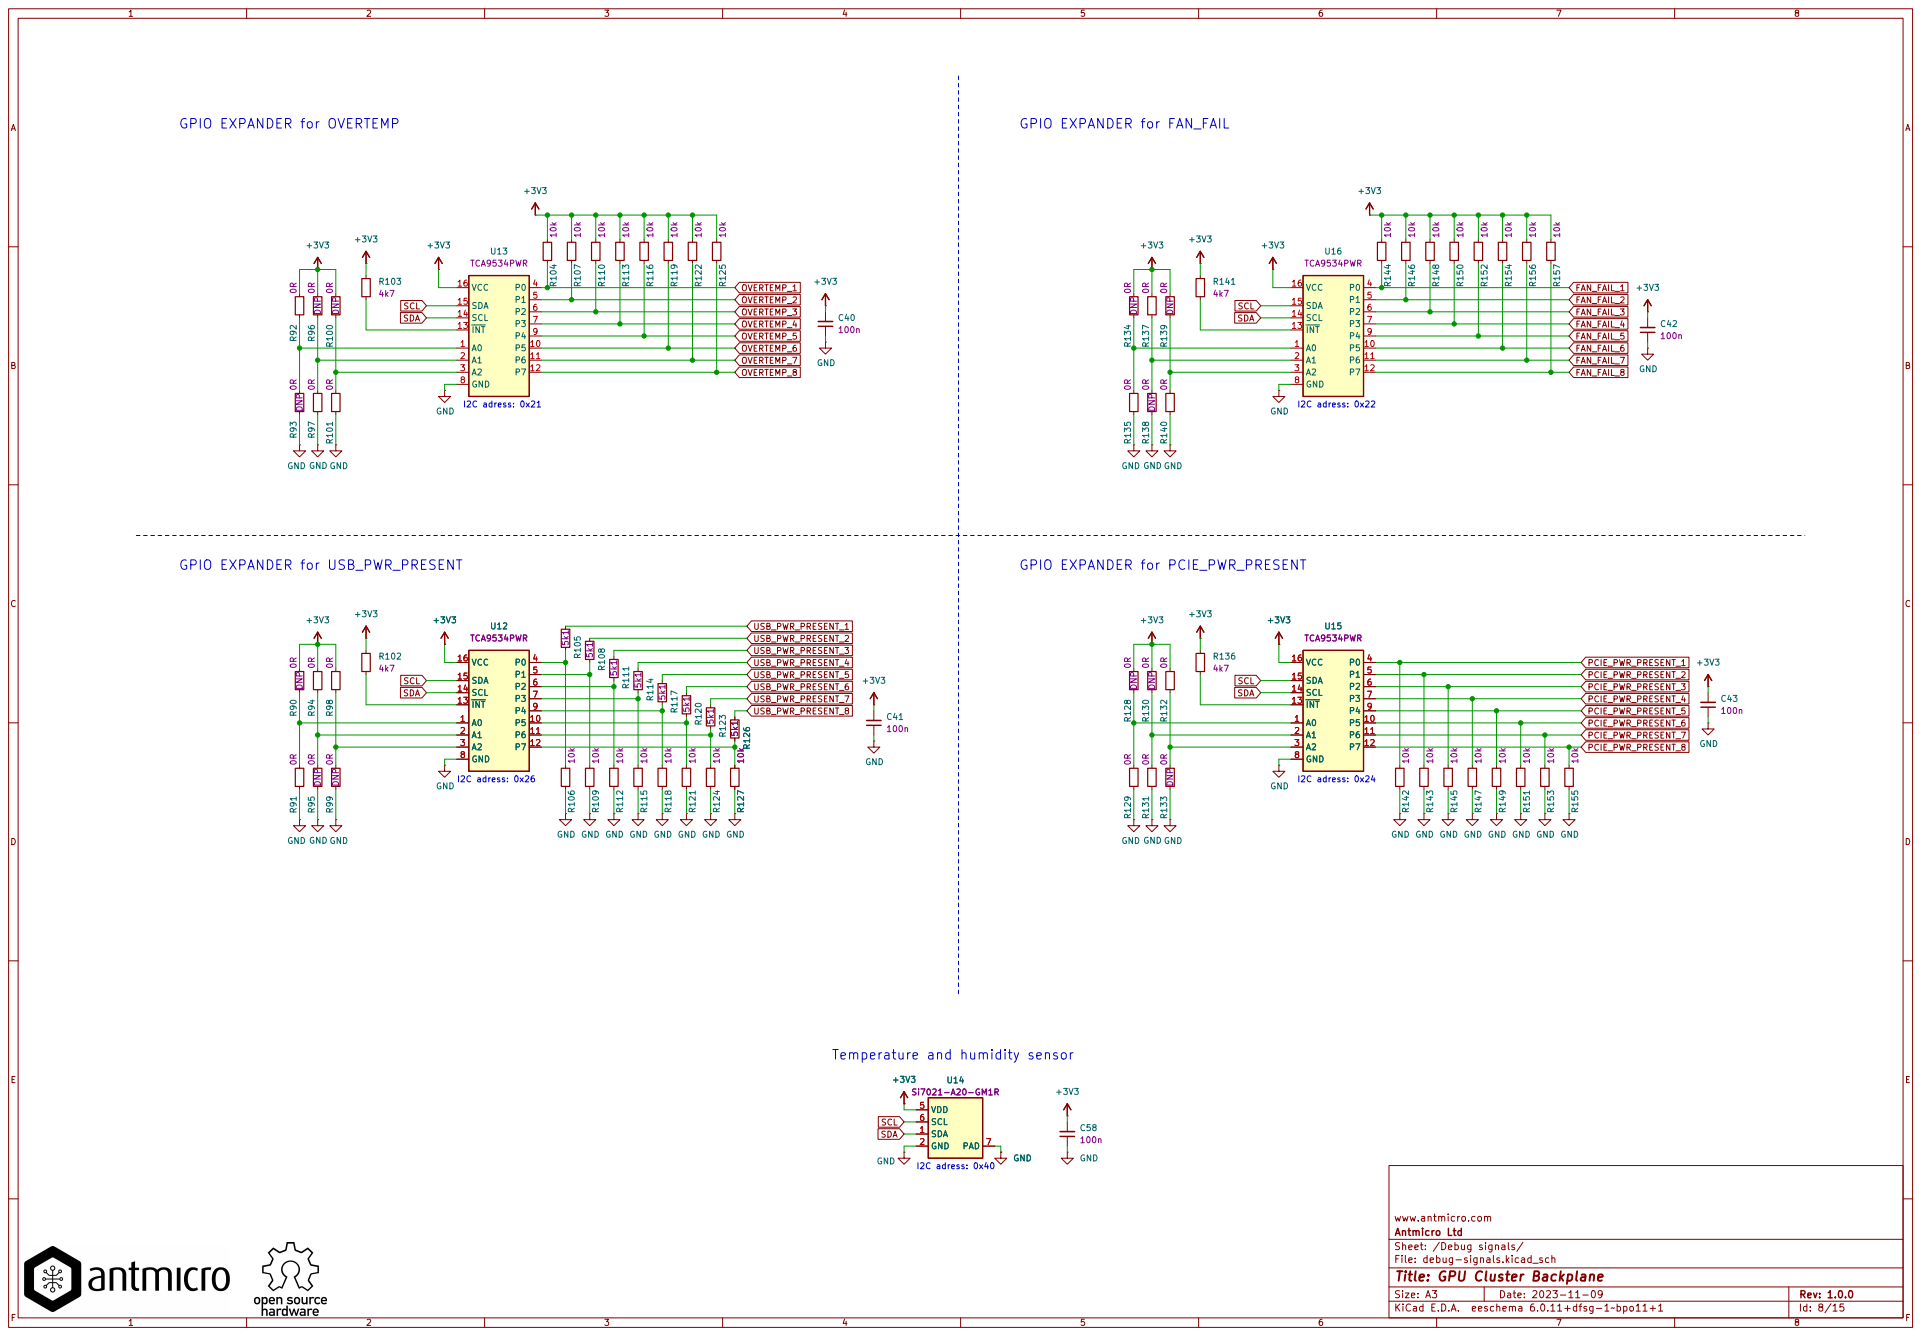
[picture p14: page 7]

Id: 8/15 Title: GPU Cluster Backplane

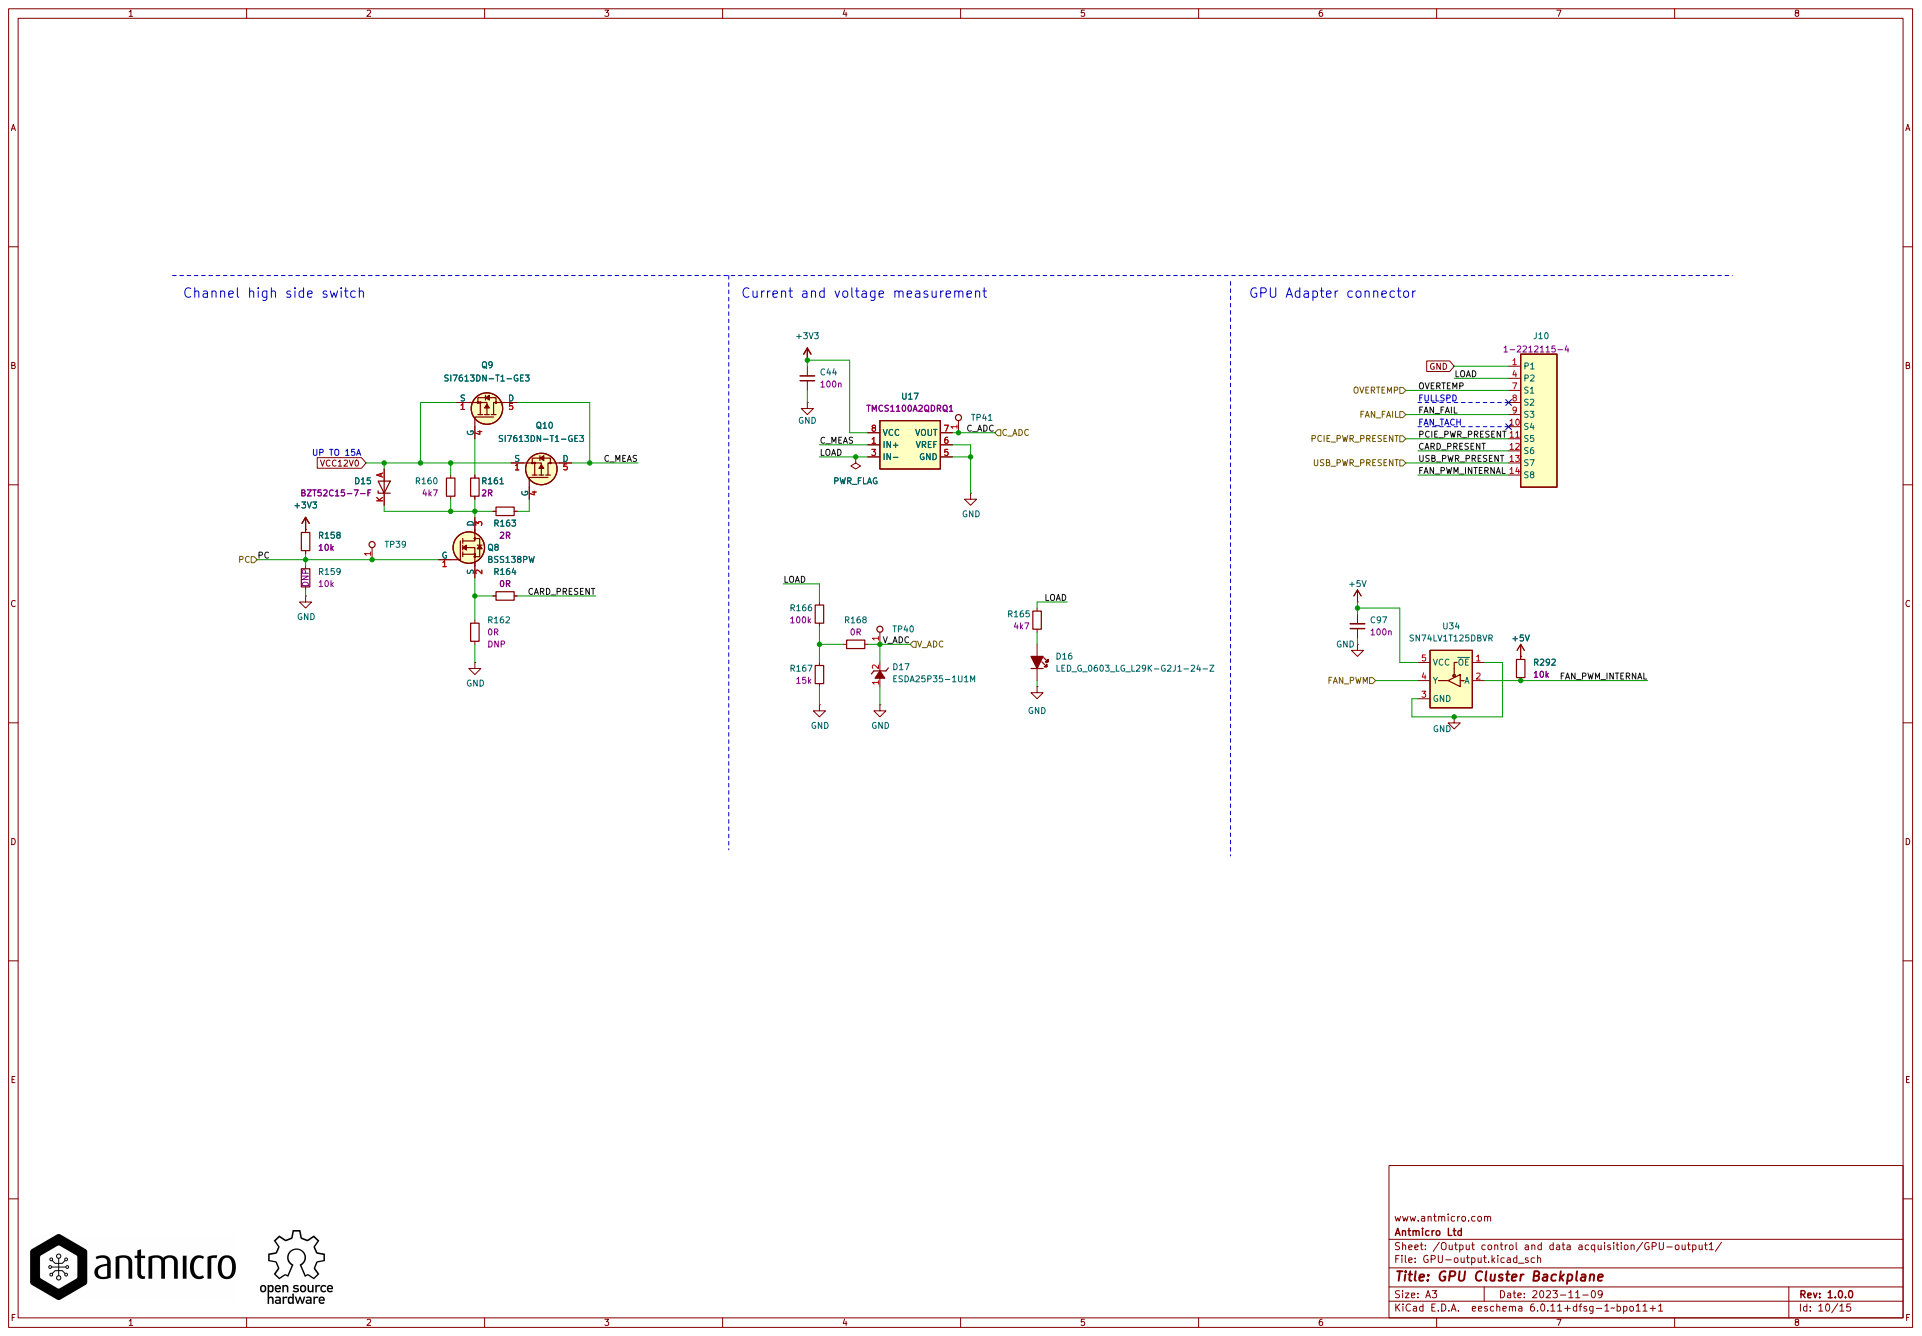
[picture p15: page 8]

Id: 10/15 Title: GPU Cluster Backplane

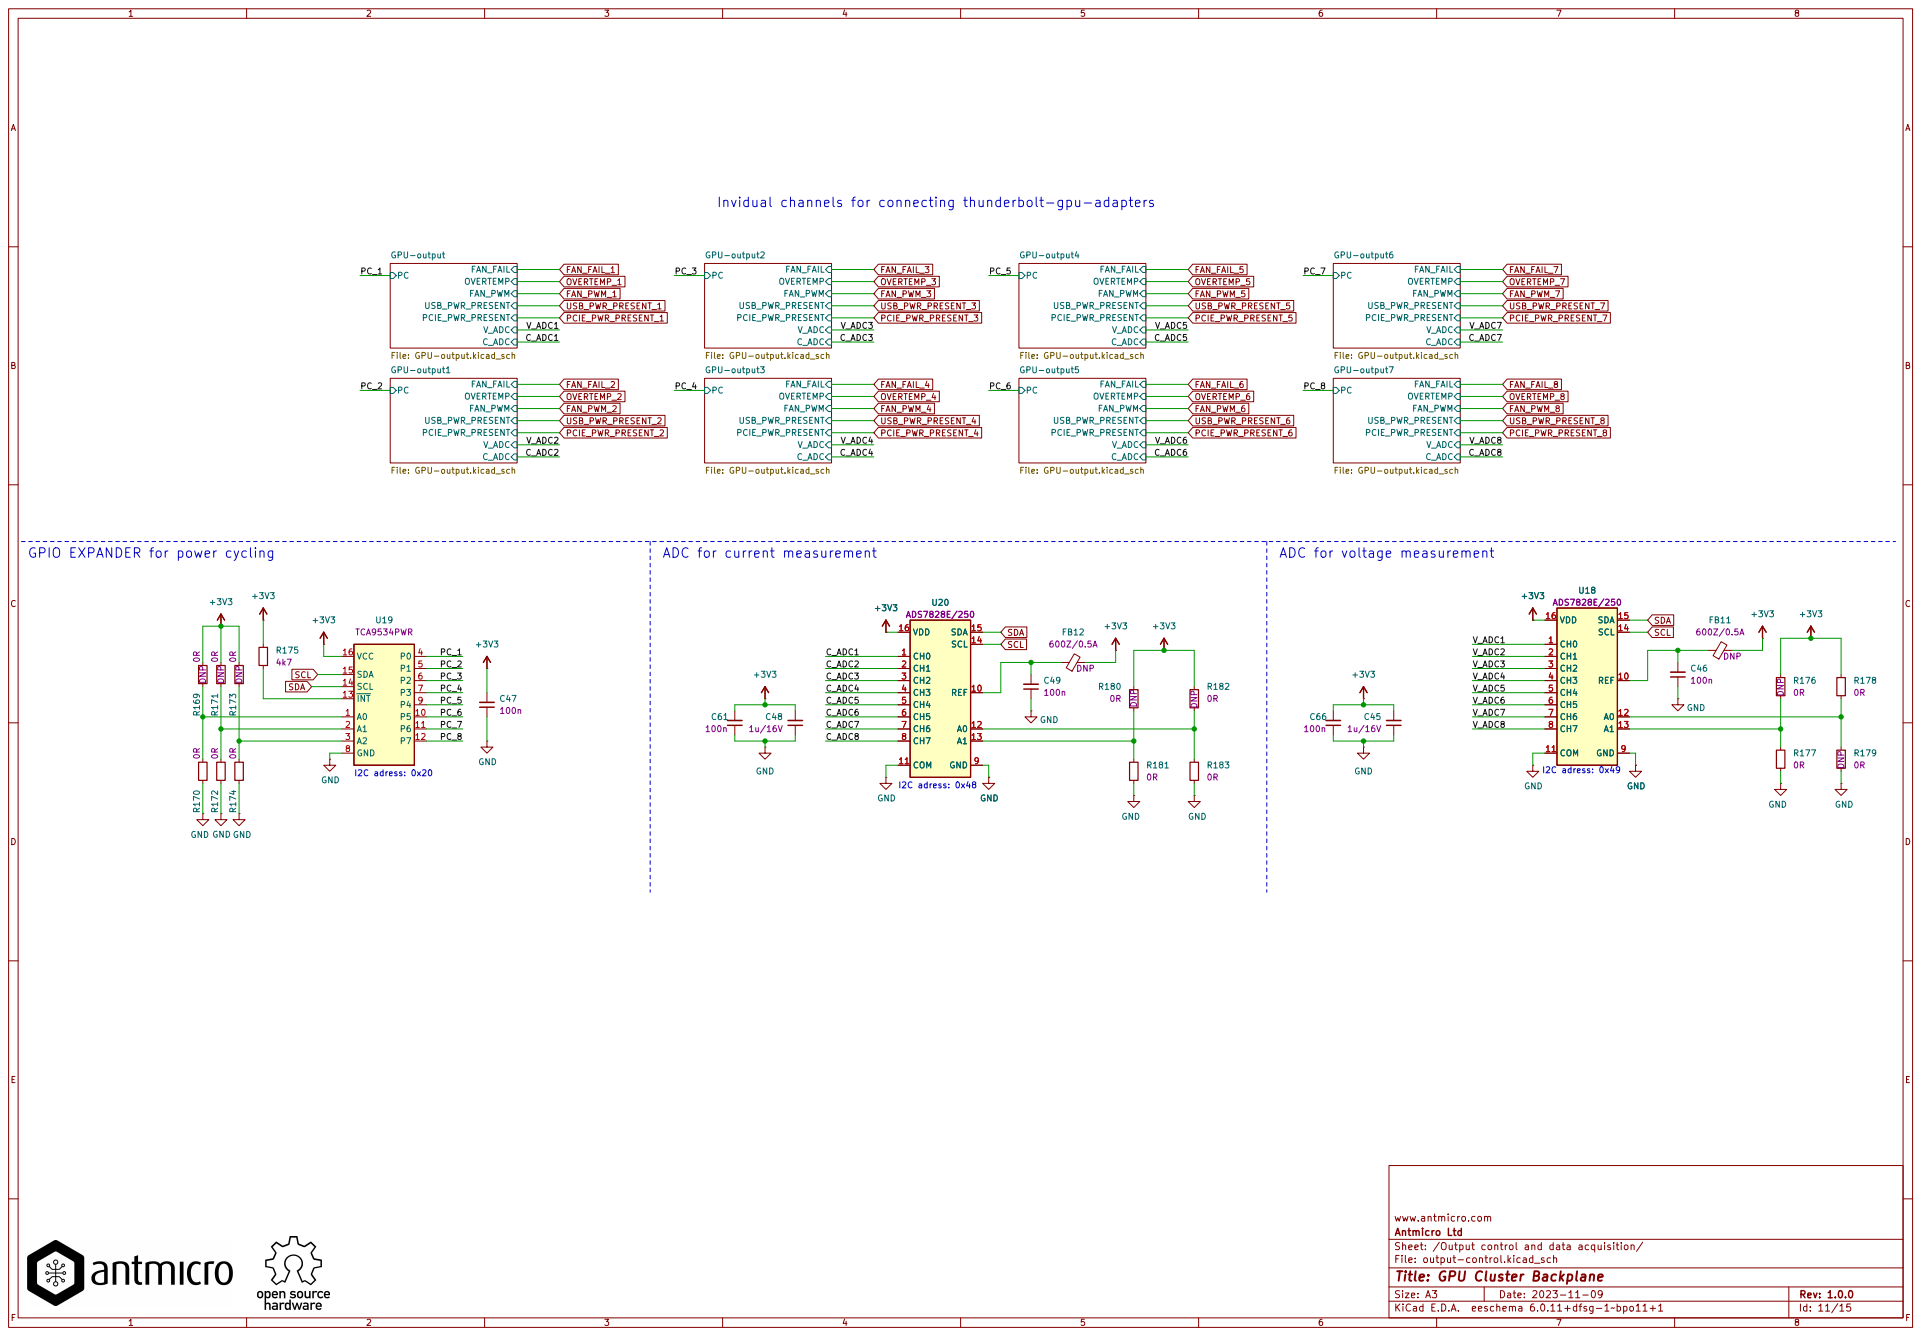
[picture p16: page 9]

I2C adress: 0x49 ADC for current measurement

Id: 11/15 Title: GPU Cluster Backplane

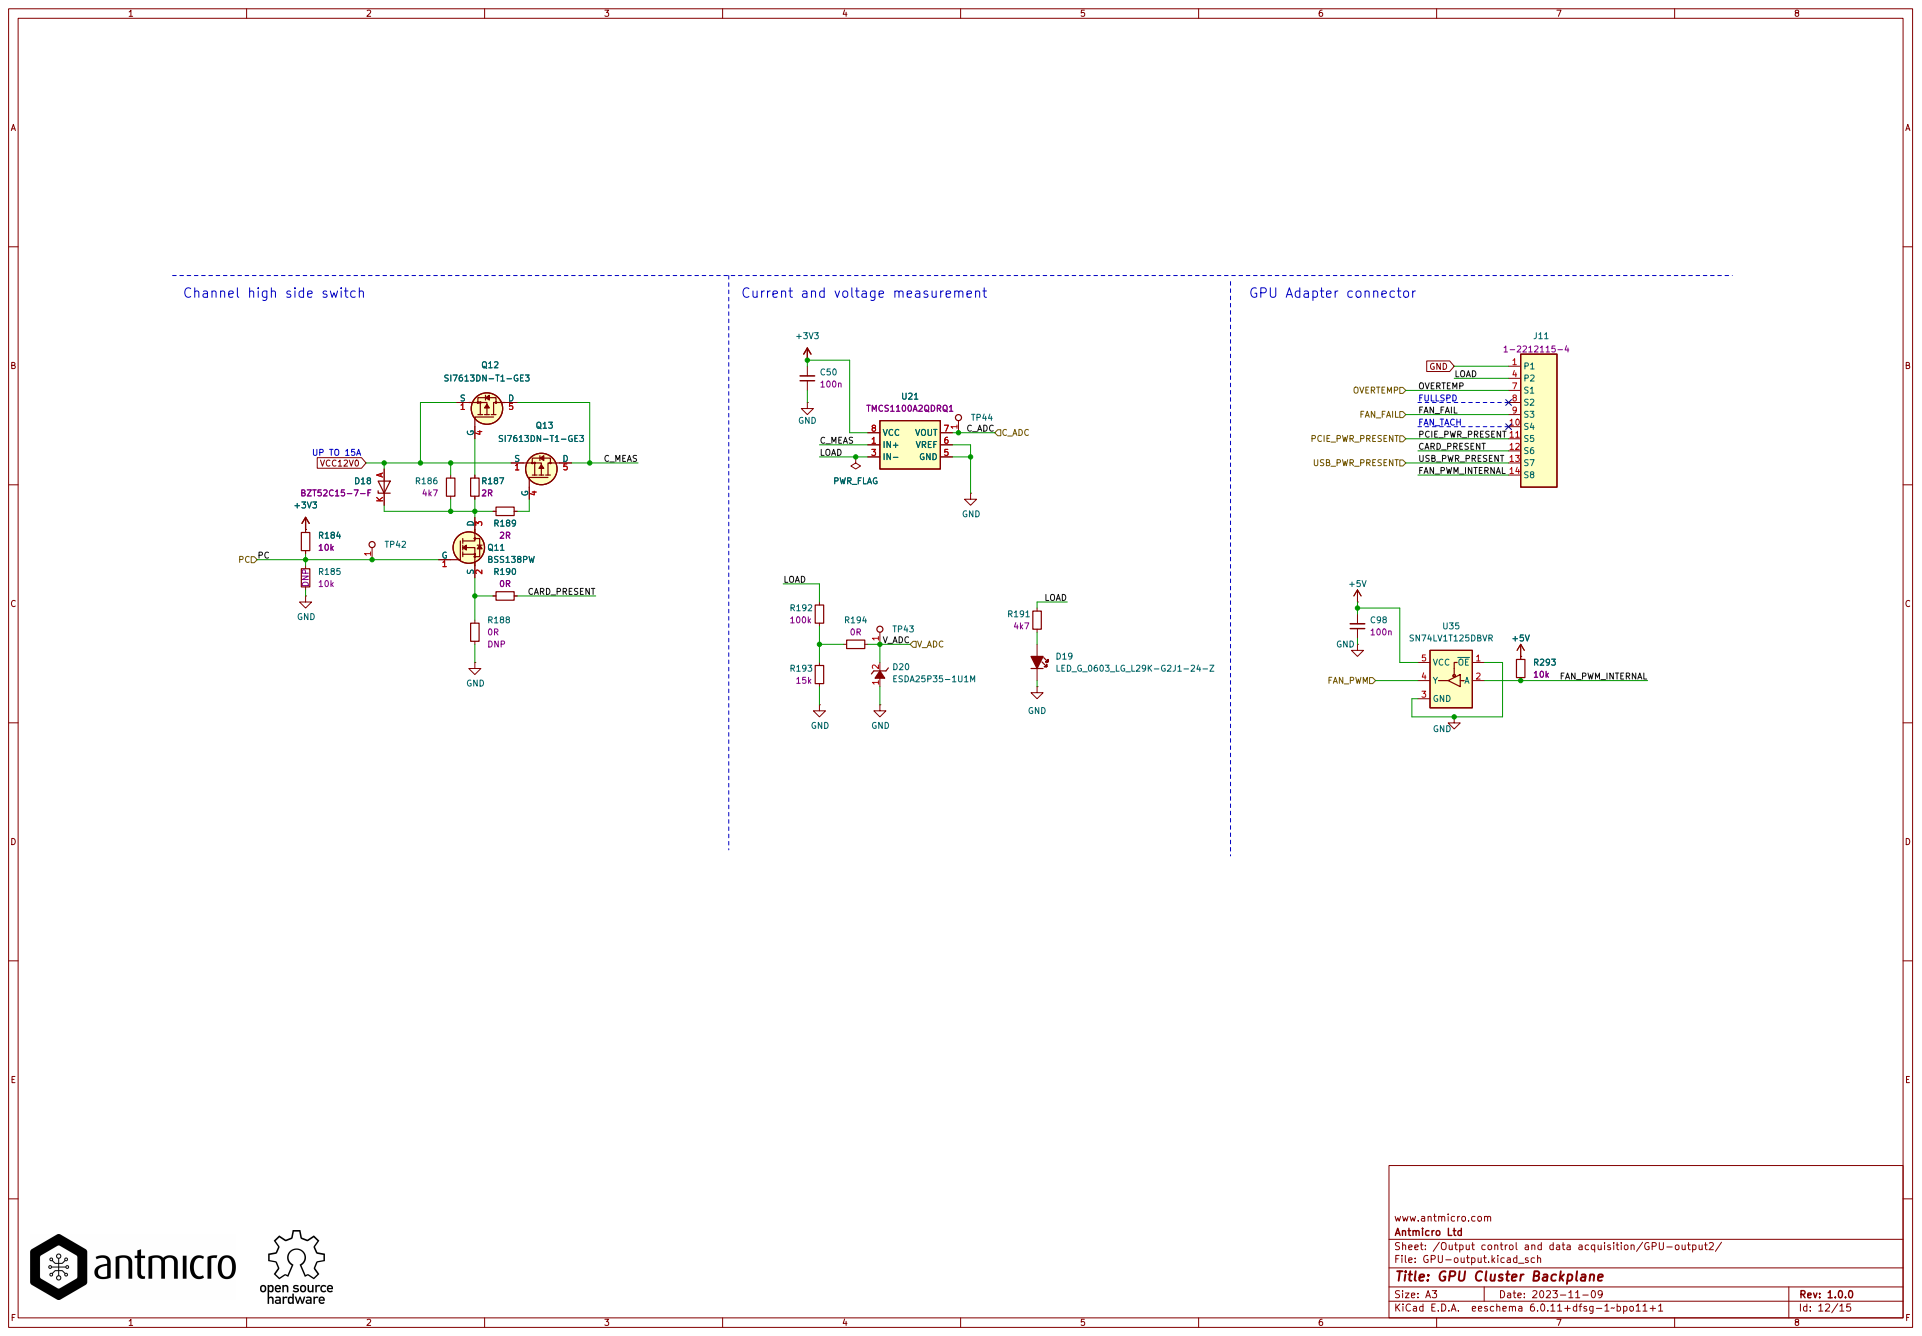
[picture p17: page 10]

Id: 12/15 Title: GPU Cluster Backplane

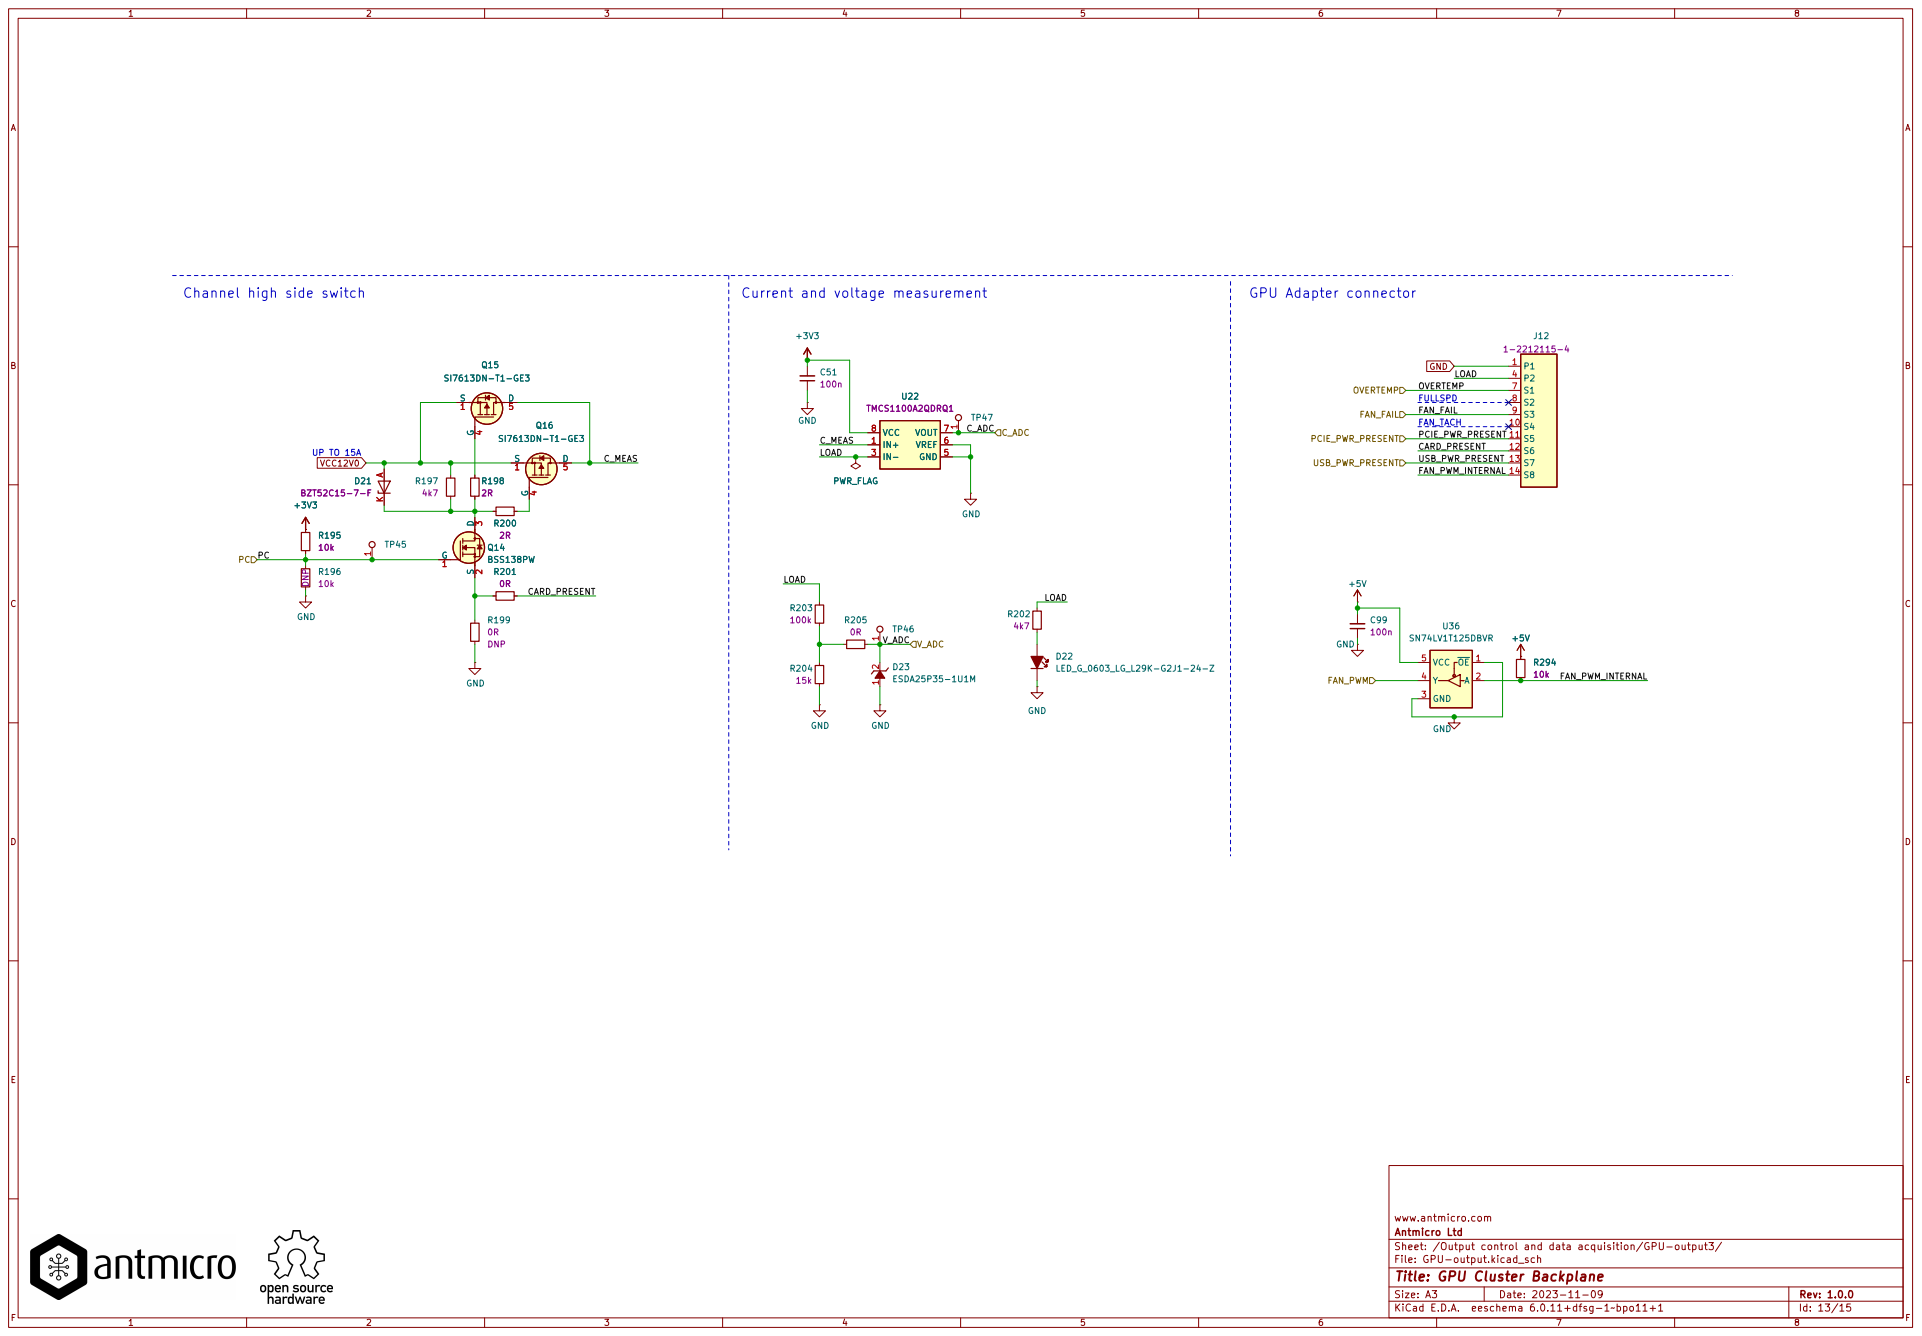
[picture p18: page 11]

Id: 13/15 Title: GPU Cluster Backplane

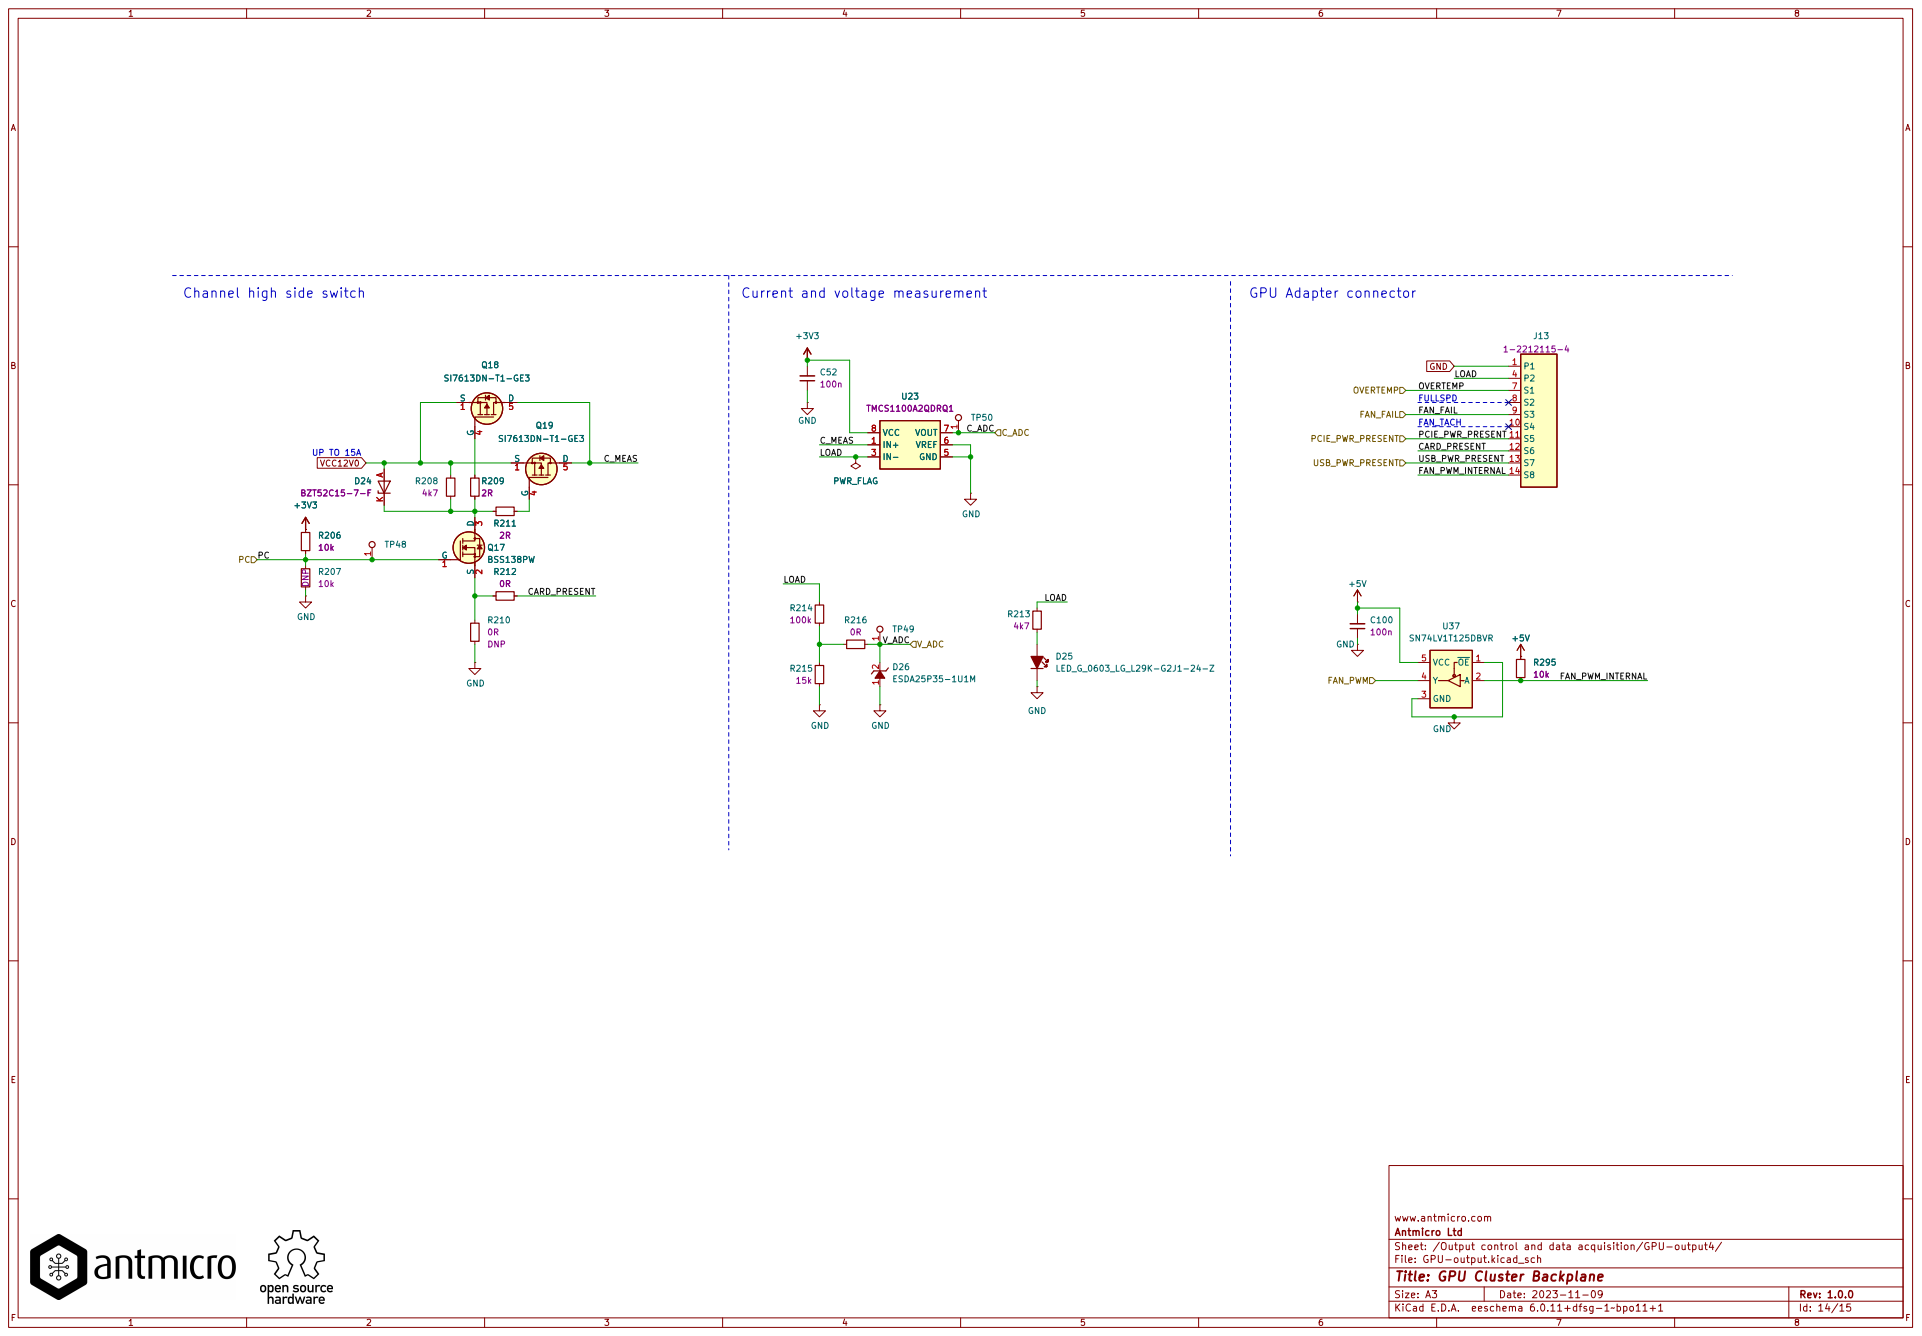
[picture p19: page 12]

Id: 14/15 Title: GPU Cluster Backplane


Id: 15/15 Title: GPU Cluster Backplane


Id: 16/15 Title: GPU Cluster Backplane


Id: 17/15 Title: GPU Cluster Backplane

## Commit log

2023-10-19 Init repo with sync from d1600e psu breakout board project
    [daughterboard-supply.kicad_sch, ftdi-module.kicad_sch, gpu-cluster-backplane.kicad_sch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]
2023-10-19 Perform globlib and find alterante components
    [daughterboard-supply.kicad_sch, ftdi-module.kicad_sch, gpu-cluster-backplane.kicad_sch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]
2023-10-23 Removing unecessary parts of the schematic
    [daughterboard-supply.kicad_sch, ftdi-module.kicad_sch, gpu-cluster-backplane.kicad_sch]
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2023-10-24 Sch Voltage and current measurement
    [gpu-cluster-backplane.kicad_sch, voltage-and-current-measurement.kicad_sch]
2023-10-24 Updated sch power cycling section
    [connectors.kicad_sch, fans-control.kicad_sch, ftdi-module.kicad_sch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]
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2023-10-24 WIP Sch components standarization
    [connectors.kicad_sch, gpu-cluster-backplane.kicad_sch, voltage-and-current-measurement.kicad_sch]
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2023-10-25 Added debug section to schematic
    [debug-signals.kicad_sch, gpu-cluster-backplane.kicad_sch, power-cycling.kicad_sch]
2023-10-25 Updated debug signals sch
    [debug-signals.kicad_sch, gpu-cluster-backplane.kicad_sch]
2023-10-25 Added I2C temperature and humidity sensor
    [connectors.kicad_sch, debug-signals.kicad_sch, gpu-cluster-backplane.kicad_sch]
2023-10-25 Updated FTDI and I2C connections
    [ftdi-module.kicad_sch, gpu-cluster-backplane.kicad_sch]
2023-10-25 Added function for enabling power after insertion of the card
    [connectors.kicad_sch, gpu-cluster-backplane.kicad_sch, power-cycling.kicad_sch]
2023-10-25 Replaced linear stabilizator with DCDC converter and switched power source from USB to 12V from PSU
    [ftdi-module.kicad_sch, gpu-cluster-backplane.kicad_sch]
2023-10-25 Removed separation of the GND signals
    [connectors.kicad_sch, gpu-cluster-backplane.kicad_sch]
2023-10-25 Updated signals on connectors to gpu adapters
    [connectors.kicad_sch, gpu-cluster-backplane.kicad_sch]
2023-10-25 WIP Working on fans control circuitry
    [fans-control.kicad_sch, gpu-cluster-backplane.kicad_sch]
2023-10-26 Corrected nets to off sheet connectors
    [debug-signals.kicad_sch, ftdi-module.kicad_sch]
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2023-10-26 Added environmental sensor to the schematic
    [connectors.kicad_sch, environmental_sensor.kicad_sch, gpu-cluster-backplane.kicad_sch]
2023-10-26 Proposed arbiter for controlling fans
    [connectors.kicad_sch, fans-control.kicad_sch, ftdi-module.kicad_sch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]
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2023-10-27 Mock placement of all components on schematic
    [connectors.kicad_sch, fans-control.kicad_sch, ftdi-module.kicad_sch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]
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2023-10-27 Change power flags on schematic
    [GPU-output.kicad_sch, connectors.kicad_sch, debug-signals.kicad_sch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]
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2023-10-27 Set resitsors to standard
    [connectors.kicad_sch, debug-signals.kicad_sch, ftdi-module.kicad_sch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]
2023-10-27 Add filtration for fan arbiters
    [fans-control.kicad_sch, gpu-cluster-backplane.kicad_sch]
2023-10-30 Repleace non standard components in connectors and ftdi and power
    [GPU-output.kicad_sch, connectors.kicad_sch, debug-signals.kicad_sch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]
2023-10-30 Standarize mechanicals and output control
    [ftdi-module.kicad_sch, gpu-cluster-backplane.kicad_sch, mechanical.kicad_sch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]
2023-10-30 Replace outpouts components
    [GPU-output.kicad_sch, gpu-cluster-backplane.kicad_sch, output-control.kicad_sch]
2023-10-30 Standarize debug signal schematic
    [GPU-output.kicad_sch, connectors.kicad_sch, debug-signals.kicad_sch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]
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2023-10-30 Standarize env sensor schematic
    [gpu-cluster-backplane.kicad_sch, nuc-compute-cluster-environment-sensor.kicad_sch]
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2023-10-30 Standarize missing components
    [GPU-output.kicad_sch, connectors.kicad_sch, debug-signals.kicad_sch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]
2023-10-30 2nd batch of standardization of schematic
    [GPU-output.kicad_sch, connectors.kicad_sch, ftdi-module.kicad_sch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]
2023-10-30 Next batch of standardization
    [GPU-output.kicad_sch, connectors.kicad_sch, fans-control.kicad_sch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]
2023-10-30 Add mux for temp signals
    [GPU-output.kicad_sch, connectors.kicad_sch, debug-signals.kicad_sch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]
2023-10-30 Replace ft4232
    [fans-control.kicad_sch, gpu-cluster-backplane.kicad_sch, nuc-compute-cluster-environment-sensor.kicad_sch]
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2023-10-31 Standarize all components and enumerate
    [GPU-output.kicad_sch, connectors.kicad_sch, debug-signals.kicad_sch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]
2023-10-31 Add fan arbiters for all outputs
    [fans-control.kicad_sch, ftdi-module.kicad_sch, gpu-cluster-backplane.kicad_sch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]
2023-11-06 Added control circuit for the casing fan
    [connectors.kicad_sch, fans-control.kicad_sch, gpu-cluster-backplane.kicad_sch]
2023-11-06 Cosmetic changes and added adnotations
    [GPU-output.kicad_sch, connectors.kicad_sch, fans-control.kicad_sch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]
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2023-11-06 Minor fixes in schematic layout and reannotate
    [GPU-output.kicad_sch, connectors.kicad_sch, debug-signals.kicad_sch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]
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2023-11-06 Redesign power LED indicator
    [connectors.kicad_sch, gpu-cluster-backplane.kicad_sch]
2023-11-06 Replace power switch connector
    [connectors.kicad_sch, gpu-cluster-backplane.kicad_sch]
2023-11-06 Replace connectord with standard alternatives
    [connectors.kicad_sch, fans-control.kicad_sch, gpu-cluster-backplane.kicad_sch]
2023-11-06 Move internal fan to correct schematic sheet
    [connectors.kicad_sch, fans-control.kicad_sch, gpu-cluster-backplane.kicad_sch]
2023-11-07 Updated project with corrcted USBC
    [GPU-output.kicad_sch, connectors.kicad_sch, debug-signals.kicad_sch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]
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2023-11-07 Replace 0603 with 0402
    [fans-control.kicad_sch, gpu-cluster-backplane.kicad_sch]
2023-11-07 Edit case fan labels
    [fans-control.kicad_sch]
2023-11-07 Raw component placement for fan control
    [GPU-output.kicad_sch]
2023-11-07 Move testpoints to hierarchical sheets
    [GPU-output.kicad_sch, gpu-cluster-backplane.kicad_sch, output-control.kicad_sch]
2023-11-07 Draft component placement for all fan control
    [GPU-output.kicad_sch, gpu-cluster-backplane.kicad_sch]
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2023-11-08 Placement of supply section on PCB
    [GPU-output.kicad_sch, connectors.kicad_sch, debug-signals.kicad_sch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]
2023-11-08 Start routing of GPIO/ADC circuit
    [GPU-output.kicad_sch, gpu-cluster-backplane.kicad_sch]
2023-11-09 Implement changes suggested in schematic review
    [GPU-output.kicad_sch, connectors.kicad_sch, debug-signals.kicad_sch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]
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2023-11-09 Fix possible ERC errors
    [connectors.kicad_sch, fans-control.kicad_sch, ftdi-module.kicad_sch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]
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2023-11-10 Fix adress on schematic
    [debug-signals.kicad_sch]
2023-11-14 Route fan signals for channel 1 and 2
    [gpu-cluster-backplane.kicad_sch, nuc-compute-cluster-environment-sensor.kicad_sch]
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2023-11-14 Replace USB on schematic
    [gpu-cluster-backplane.kicad_sch, nuc-compute-cluster-environment-sensor.kicad_sch]
2023-11-14 Fix ERC errors
    [GPU-output.kicad_sch, connectors.kicad_sch, debug-signals.kicad_sch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]
2023-11-14 Fix ESD diode symbol and GPU connector symbol
    [GPU-output.kicad_sch, connectors.kicad_sch, ftdi-module.kicad_sch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]
2023-11-14 Solver ERC errors
    [nuc-compute-cluster-environment-sensor.kicad_sch]
2023-11-15 Replace symbols with alternatives from main component library
    [GPU-output.kicad_sch, connectors.kicad_sch, debug-signals.kicad_sch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]
2023-11-15 Replace GPU edge connector
    [GPU-output.kicad_sch, gpu-cluster-backplane.kicad_sch]
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2023-11-16 Replace footprints for env sensor
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2023-11-16 Replace USB for env sensor
    [gpu-cluster-backplane.kicad_sch, nuc-compute-cluster-environment-sensor.kicad_sch]
2023-11-16 Update schematic with corrected symbols
    [GPU-output.kicad_sch, nuc-compute-cluster-environment-sensor.kicad_sch]
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
